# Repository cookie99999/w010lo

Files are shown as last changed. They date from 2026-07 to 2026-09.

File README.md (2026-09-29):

# A homebrew MC68010 computer

### Current specs:

- 16MHz 68010
- 1MB RAM
- 256K flash
- 68681 DUART
- A simple monitor ported from my 65816 computer, with XMODEM download support
- PATA interface (tested with several CF cards and a real IDE HDD)

### Todo:

- New PCB revision with some bodge fixes and some SMD parts to fit more memory
- Real-time clock
- Audio+video board
- PS/2 mouse + keyboard controller
- Consider networking (SLIP or ethernet controller)

### Toolchain notes

For assembly I am using vasm, since I like the syntax better than GAS. For C, I built a cross-compiling GCC and binutils from source. When configuring GCC for a 68000/68008/68010 target, you have to be careful not to let it use any 68020+ or FPU specific instructions, or else your libgcc won't work. Here's the line I used to configure mine:
```
../gcc-15.2.0/configure --prefix=/home/cookie/.local/ --program-prefix=m68k-elf- --target=m68k-elf --with-cpu=m68000 --enable-languages=c --with-newlib --disable-libssp --disable-libgomp --disable-threads --disable-multilib --disable-nls --disable-libquadmath --without-headers --disable-m68020 --disable-m68881
```
Some of the less obvious options may not be strictly necessary, I haven't tested with and without each one.
With just a compiler, binutils, and libgcc, you have pretty much all you need to comfortably write and use C programs. I have ported newlib+libgloss, but have some minor bugs to work out. I will eventually write up the process, as a lot of the documentation online is outdated by this point.

###

Shoutout to [aslak](https://www.aslak.net/), [rosco-m68k](https://github.com/rosco-m68k), [68-Katy](https://www.bigmessowires.com/68-katy/), [Matt Sarnoff](https://github.com/74hc595/68k-nano), [Jeff Tranter](https://jefftranter.blogspot.com/), and [Mackerel-68k](https://hackaday.io/project/183861-mackerel-68k-linux-sbcs) for their inspiring projects and helpful logs.

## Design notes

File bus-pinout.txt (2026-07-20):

96 Pin 3x32 DIN 41612
A       | B      | C
--------------------------
D0      | NC     | D8
D1      | NC     | D9
D2      | NC     | D10
D3      | NC     | D11
D4      | NC     | D12
D5      | NC     | D13
D6      | NC     | D14
D7      | NC     | D15
GND     | NC     | GND
CLK     | NC     | NC
GND     | NC     | !BERR
!UDS    | NC     | !RESET
!LDS    | NC     | NC
R/!W    | NC     | NC
GND     | NC     | A23
!DTACK  | GND    | A22
GND     | !VMA   | A21
!AS     | E      | A20
GND     | !VPA   | A19
!IACK   | GND    | A18
!IACKIN | NC     | A17
!IACKOUT| NC     | A16
NC      | GND    | A15
A7      | !IRQ7  | A14
A6      | !IRQ6  | A13
A5      | !IRQ5  | A12
A4      | !IRQ4  | A11
A3      | !IRQ3  | A10
A2      | !IRQ2  | A9
A1      | !IRQ1  | A8
NC      | +5V    | NC
+5V     | +5V    | +5V

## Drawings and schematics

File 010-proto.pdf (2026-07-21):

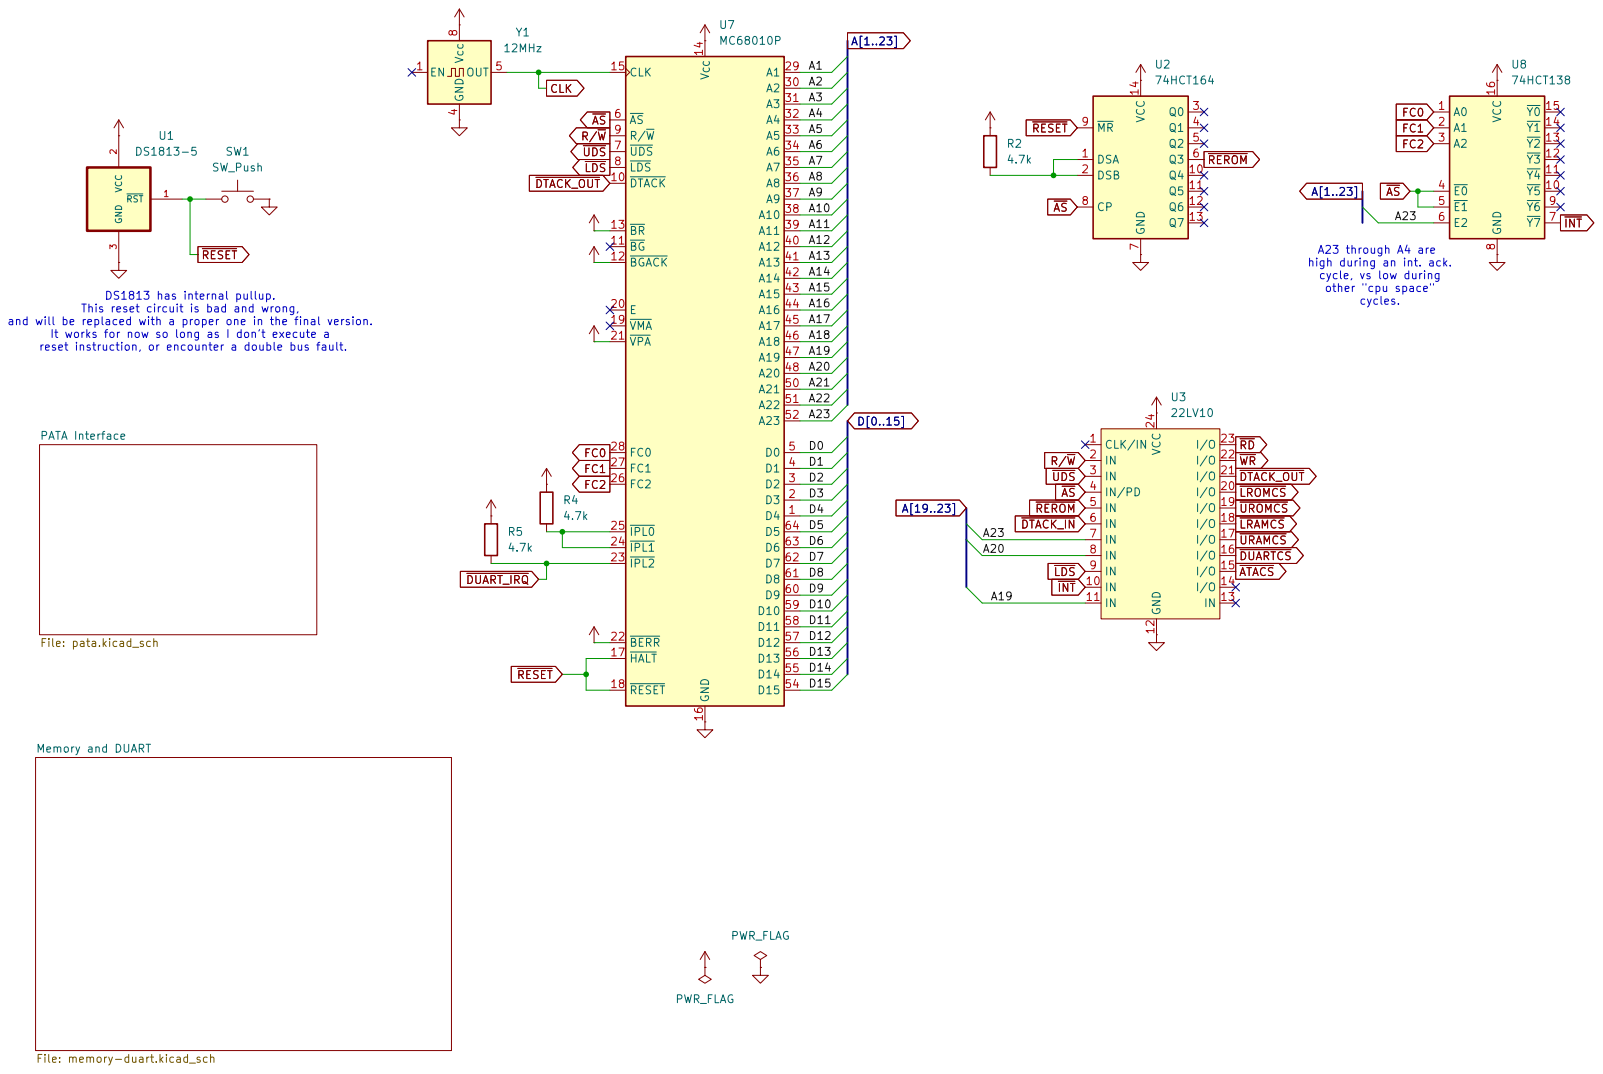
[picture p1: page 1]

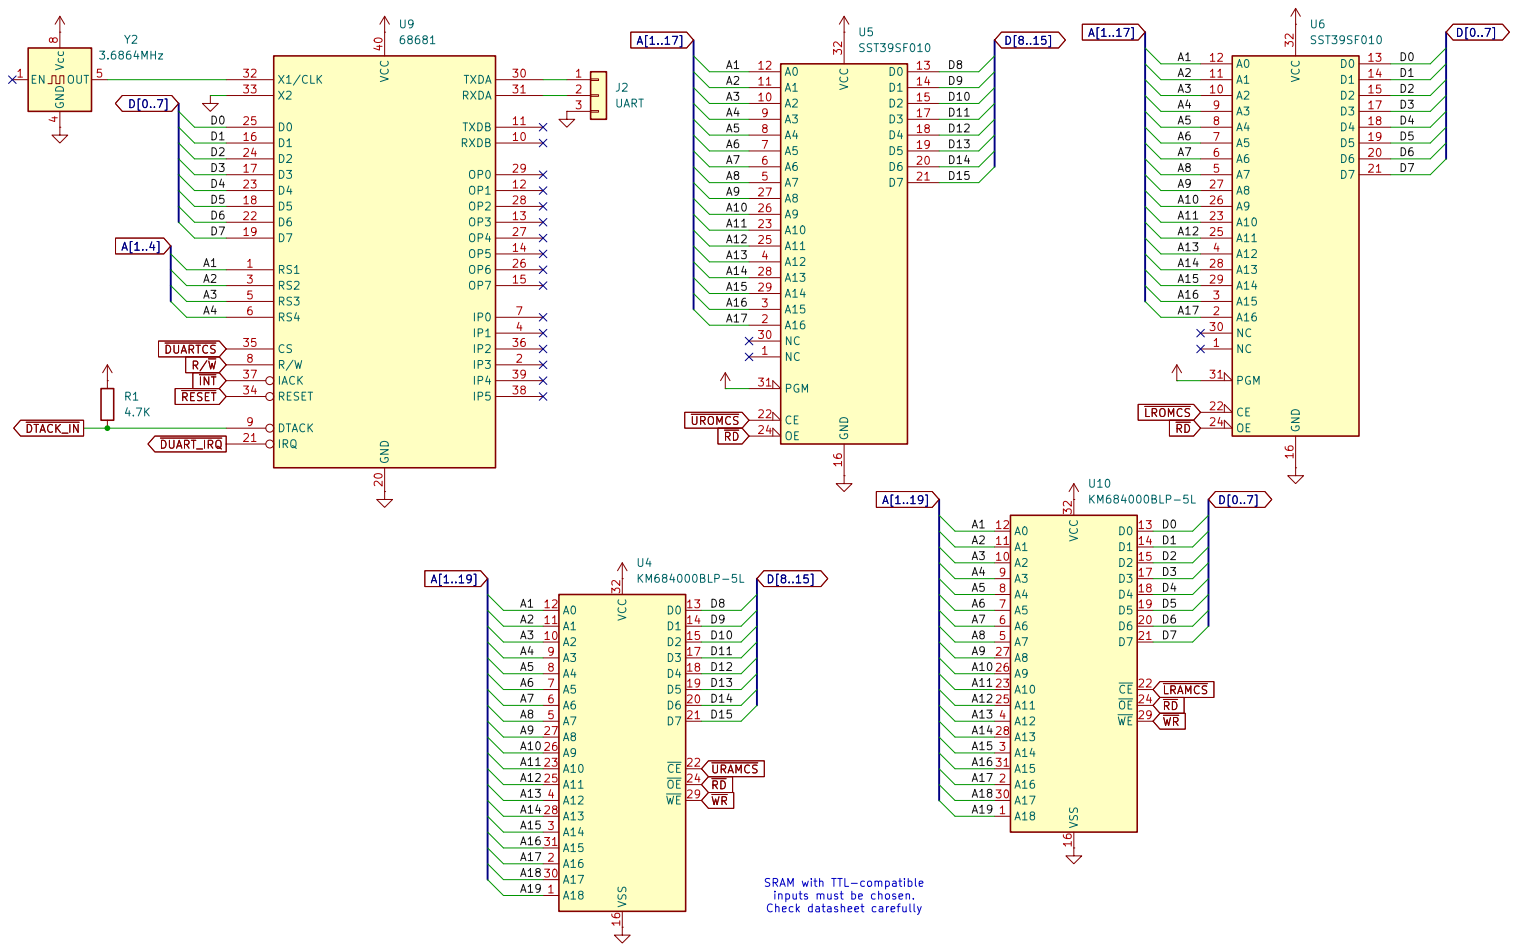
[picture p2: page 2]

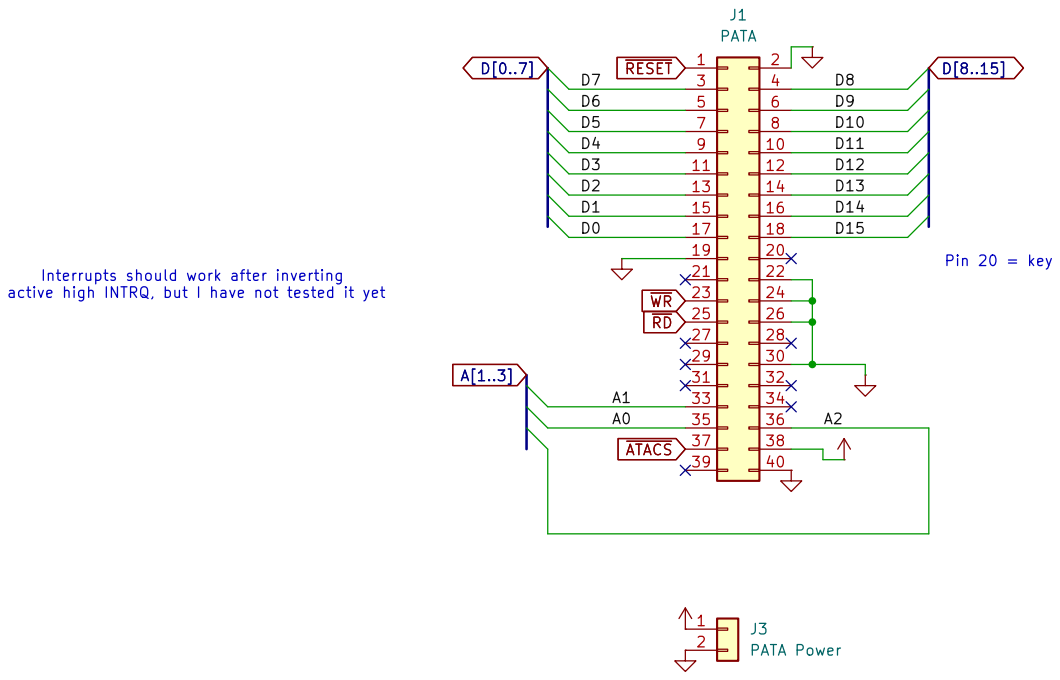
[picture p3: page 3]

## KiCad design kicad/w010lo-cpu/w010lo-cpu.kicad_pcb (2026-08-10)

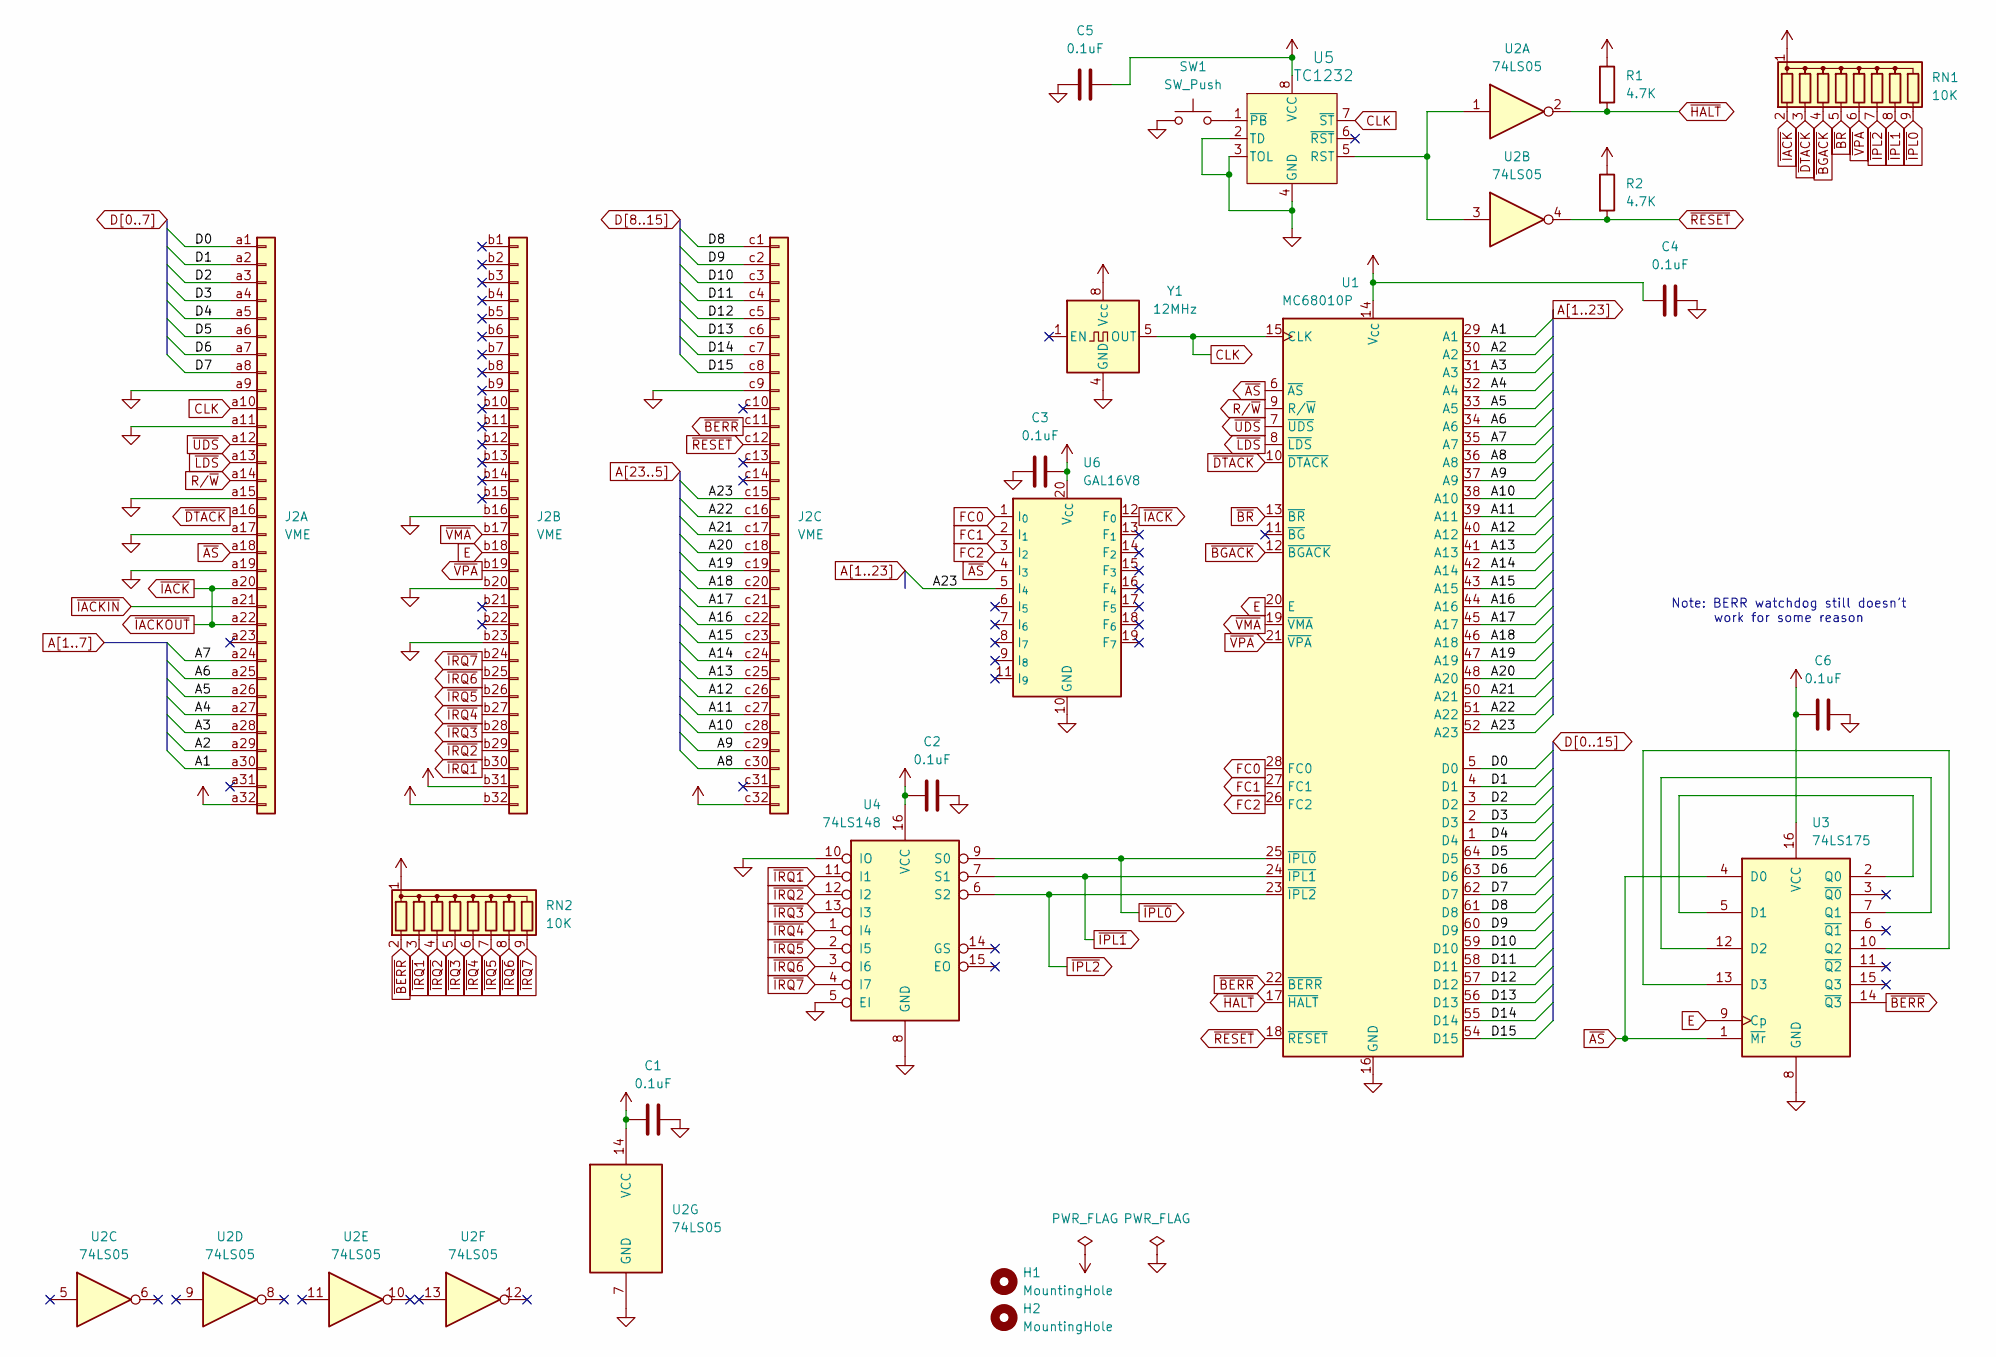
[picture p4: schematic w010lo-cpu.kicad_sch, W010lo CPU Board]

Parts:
C1, C2, C3, C4, C5, C6: 0.1uF; C_Disc_D5.0mm_W2.5mm_P5.00mm
H1, H2: MountingHole; MountingHole_3.2mm_M3
J2: VME; DIN41612_C_3x32_Male_Horizontal_THT
R1, R2: 4.7K; R_Axial_DIN0204_L3.6mm_D1.6mm_P5.08mm_Horizontal
RN1, RN2: 10K; R_Array_SIP9
SW1: SW_Push; SW_TS11-674-135-BK-160-RA-D
U1: MC68010P; DIP-64_W22.86mm
U2: 74LS05; DIP-14_W7.62mm_Socket
U3: 74LS175; DIP-16_W7.62mm_Socket
U4: 74LS148; DIP-16_W7.62mm_Socket
U5: TC1232; DIP-8_W7.62mm_Socket
U6: GAL16V8; DIP-20_W7.62mm_Socket
Y1: 12MHz; Oscillator_DIP-8

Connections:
A1: J2.a30, U1.29 (A1)
A2: J2.a29, U1.30 (A2)
A3: J2.a28, U1.31 (A3)
A4: J2.a27, U1.32 (A4)
A5: J2.a26, U1.33 (A5)
A6: J2.a25, U1.34 (A6)
A7: J2.a24, U1.35 (A7)
A8: J2.c30, U1.36 (A8)
A9: J2.c29, U1.37 (A9)
A10: J2.c28, U1.38 (A10)
A11: J2.c27, U1.39 (A11)
A12: J2.c26, U1.40 (A12)
A13: J2.c25, U1.41 (A13)
A14: J2.c24, U1.42 (A14)
A15: J2.c23, U1.43 (A15)
A16: J2.c22, U1.44 (A16)
A17: J2.c21, U1.45 (A17)
A18: J2.c20, U1.46 (A18)
A19: J2.c19, U1.47 (A19)
A20: J2.c18, U1.48 (A20)
A21: J2.c17, U1.50 (A21)
A22: J2.c16, U1.51 (A22)
A23: J2.c15, U1.52 (A23), U6.5 (I_{4})
CLK: J2.a10, U1.15 (CLK), U5.7 (~ST), Y1.5 (OUT)
D0: J2.a1, U1.5 (D0)
D1: J2.a2, U1.4 (D1)
D2: J2.a3, U1.3 (D2)
D3: J2.a4, U1.2 (D3)
D4: J2.a5, U1.1 (D4)
D5: J2.a6, U1.64 (D5)
D6: J2.a7, U1.63 (D6)
D7: J2.a8, U1.62 (D7)
D8: J2.c1, U1.61 (D8)
D9: J2.c2, U1.60 (D9)
D10: J2.c3, U1.59 (D10)
D11: J2.c4, U1.58 (D11)
D12: J2.c5, U1.57 (D12)
D13: J2.c6, U1.56 (D13)
D14: J2.c7, U1.55 (D14)
D15: J2.c8, U1.54 (D15)
E: J2.b18, U1.20 (E), U3.9 (Cp)
FC0: U1.28 (FC0), U6.1 (I_{0})
FC1: U1.27 (FC1), U6.2 (I_{1})
FC2: U1.26 (FC2), U6.3 (I_{2})
GND: C1.2, C2.2, C3.2, C4.2, C5.2, C6.2, J2.a9, J2.a11, J2.a15, J2.a17, J2.a19, J2.b16, J2.b20, J2.b23, J2.c9, SW1.1, U1.16 (GND), U1.53 (GND), U2.7 (GND), U3.8 (GND), U4.5 (EI), U4.8 (GND), U4.10 (IO), U5.2 (TD), U5.3 (TOL), U5.4 (GND), U6.10 (GND), Y1.4 (GND)
unnamed: U3.2 (Q0), U3.5 (D1)
unnamed: U3.7 (Q1), U3.12 (D2)
unnamed: U3.10 (Q2), U3.13 (D3)
unnamed: U2.1, U2.3, U5.5 (RST)
unnamed: SW1.2, U5.1 (~PB)
R/~W: J2.a14, U1.9 (R/~W)
VCC: C1.1, C2.1, C3.1, C4.1, C5.1, C6.1, J2.a32, J2.b31, J2.b32, J2.c32, R1.1, R2.1, RN1.1 (common), RN2.1 (common), U1.14 (V_{CC}), U1.49 (V_{CC}), U2.14 (VCC), U3.16 (VCC), U4.16 (VCC), U5.8 (VCC), U6.20 (V_{CC}), Y1.8 (Vcc)
~AS: J2.a18, U1.6 (~AS), U3.1 (~Mr), U3.4 (D0), U6.4 (I_{3})
~BERR: J2.c11, RN2.2 (R1), U1.22 (~BERR), U3.14 (~Q3)
~BGACK: RN1.4 (R3), U1.12 (~BGACK)
~BR: RN1.5 (R4), U1.13 (~BR)
~DTACK: J2.a16, RN1.3 (R2), U1.10 (~DTACK)
~HALT: R1.2, U1.17 (~HALT), U2.2
~IACKIN: J2.a21
~IACKOUT: J2.a20, J2.a22, RN1.2 (R1), U6.12 (F_{0})
~IPL0: RN1.9 (R8), U1.25 (~IPL0), U4.9 (S0)
~IPL1: RN1.8 (R7), U1.24 (~IPL1), U4.7 (S1)
~IPL2: RN1.7 (R6), U1.23 (~IPL2), U4.6 (S2)
~IRQ1: J2.b30, RN2.3 (R2), U4.11 (I1)
~IRQ2: J2.b29, RN2.4 (R3), U4.12 (I2)
~IRQ3: J2.b28, RN2.5 (R4), U4.13 (I3)
~IRQ4: J2.b27, RN2.6 (R5), U4.1 (I4)
~IRQ5: J2.b26, RN2.7 (R6), U4.2 (I5)
~IRQ6: J2.b25, RN2.8 (R7), U4.3 (I6)
~IRQ7: J2.b24, RN2.9 (R8), U4.4 (I7)
~LDS: J2.a13, U1.8 (~LDS)
~RESET: J2.c12, R2.2, U1.18 (~RESET), U2.4
~UDS: J2.a12, U1.7 (~UDS)
~VMA: J2.b17, U1.19 (~VMA)
~VPA: J2.b19, RN1.6 (R5), U1.21 (~VPA)

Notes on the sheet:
Note: BERR watchdog still doesn't work for some reason

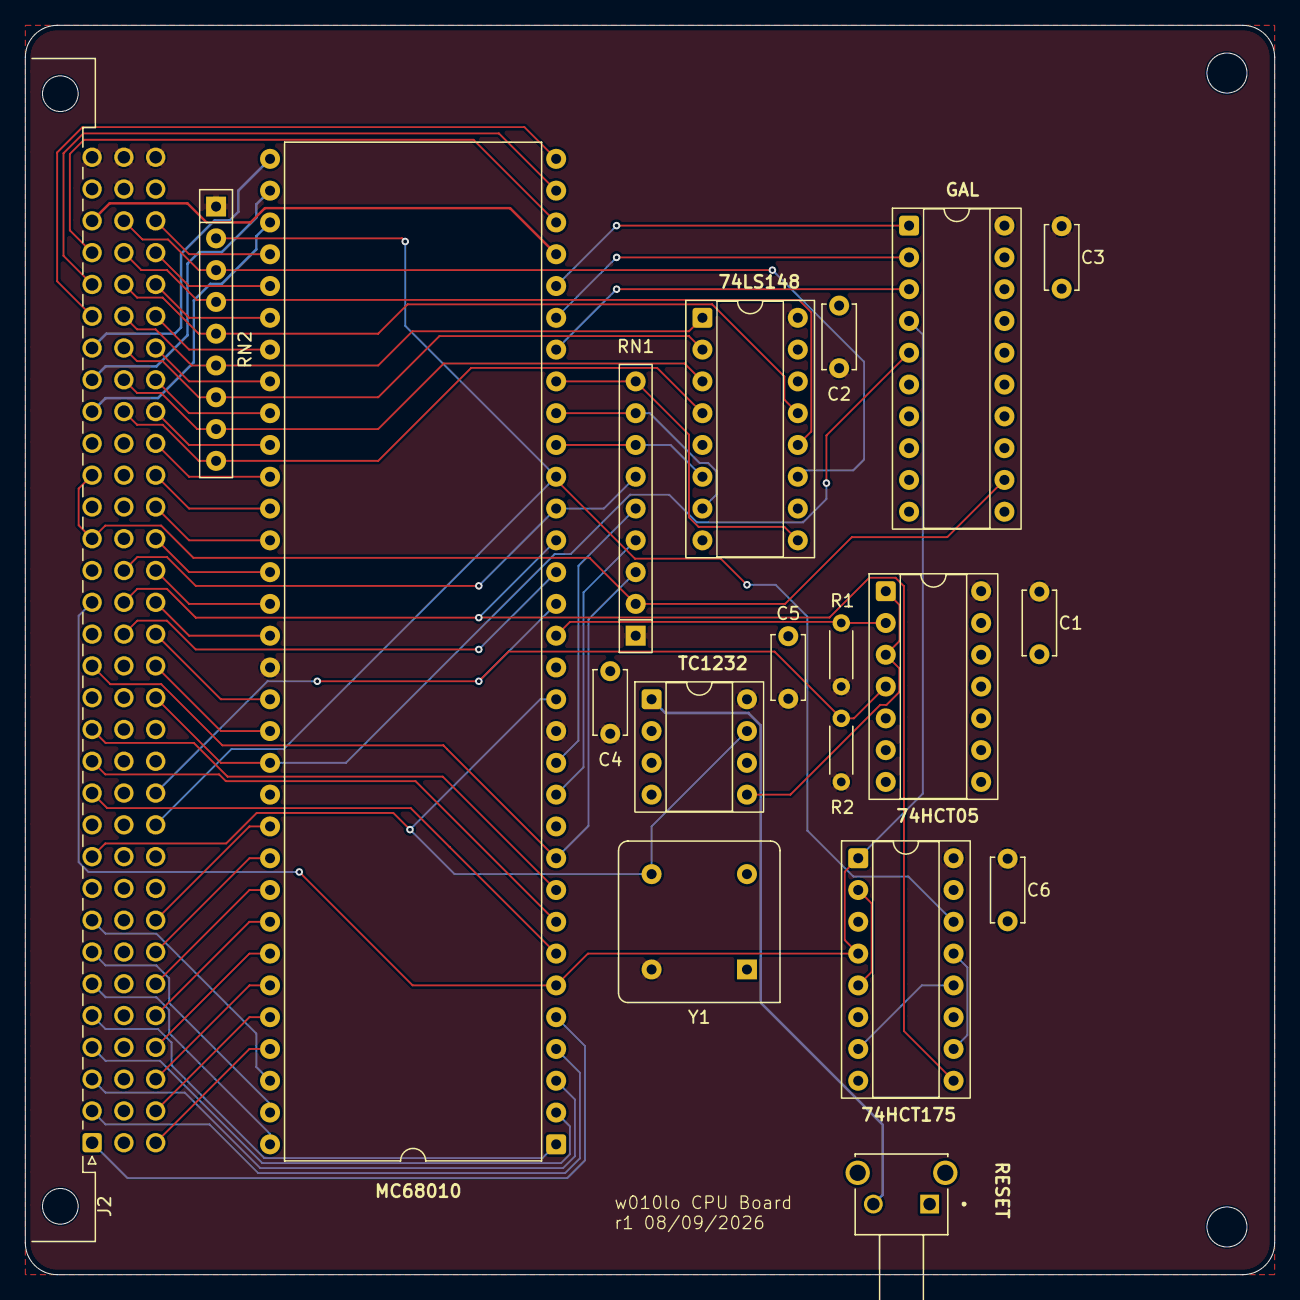
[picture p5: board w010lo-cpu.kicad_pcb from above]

Board: 4 copper layers, 99.8 x 99.8 mm, 22 parts (0 on the bottom side), 74 nets.

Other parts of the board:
H3: MountingHole; MountingHole_3.2mm_M3

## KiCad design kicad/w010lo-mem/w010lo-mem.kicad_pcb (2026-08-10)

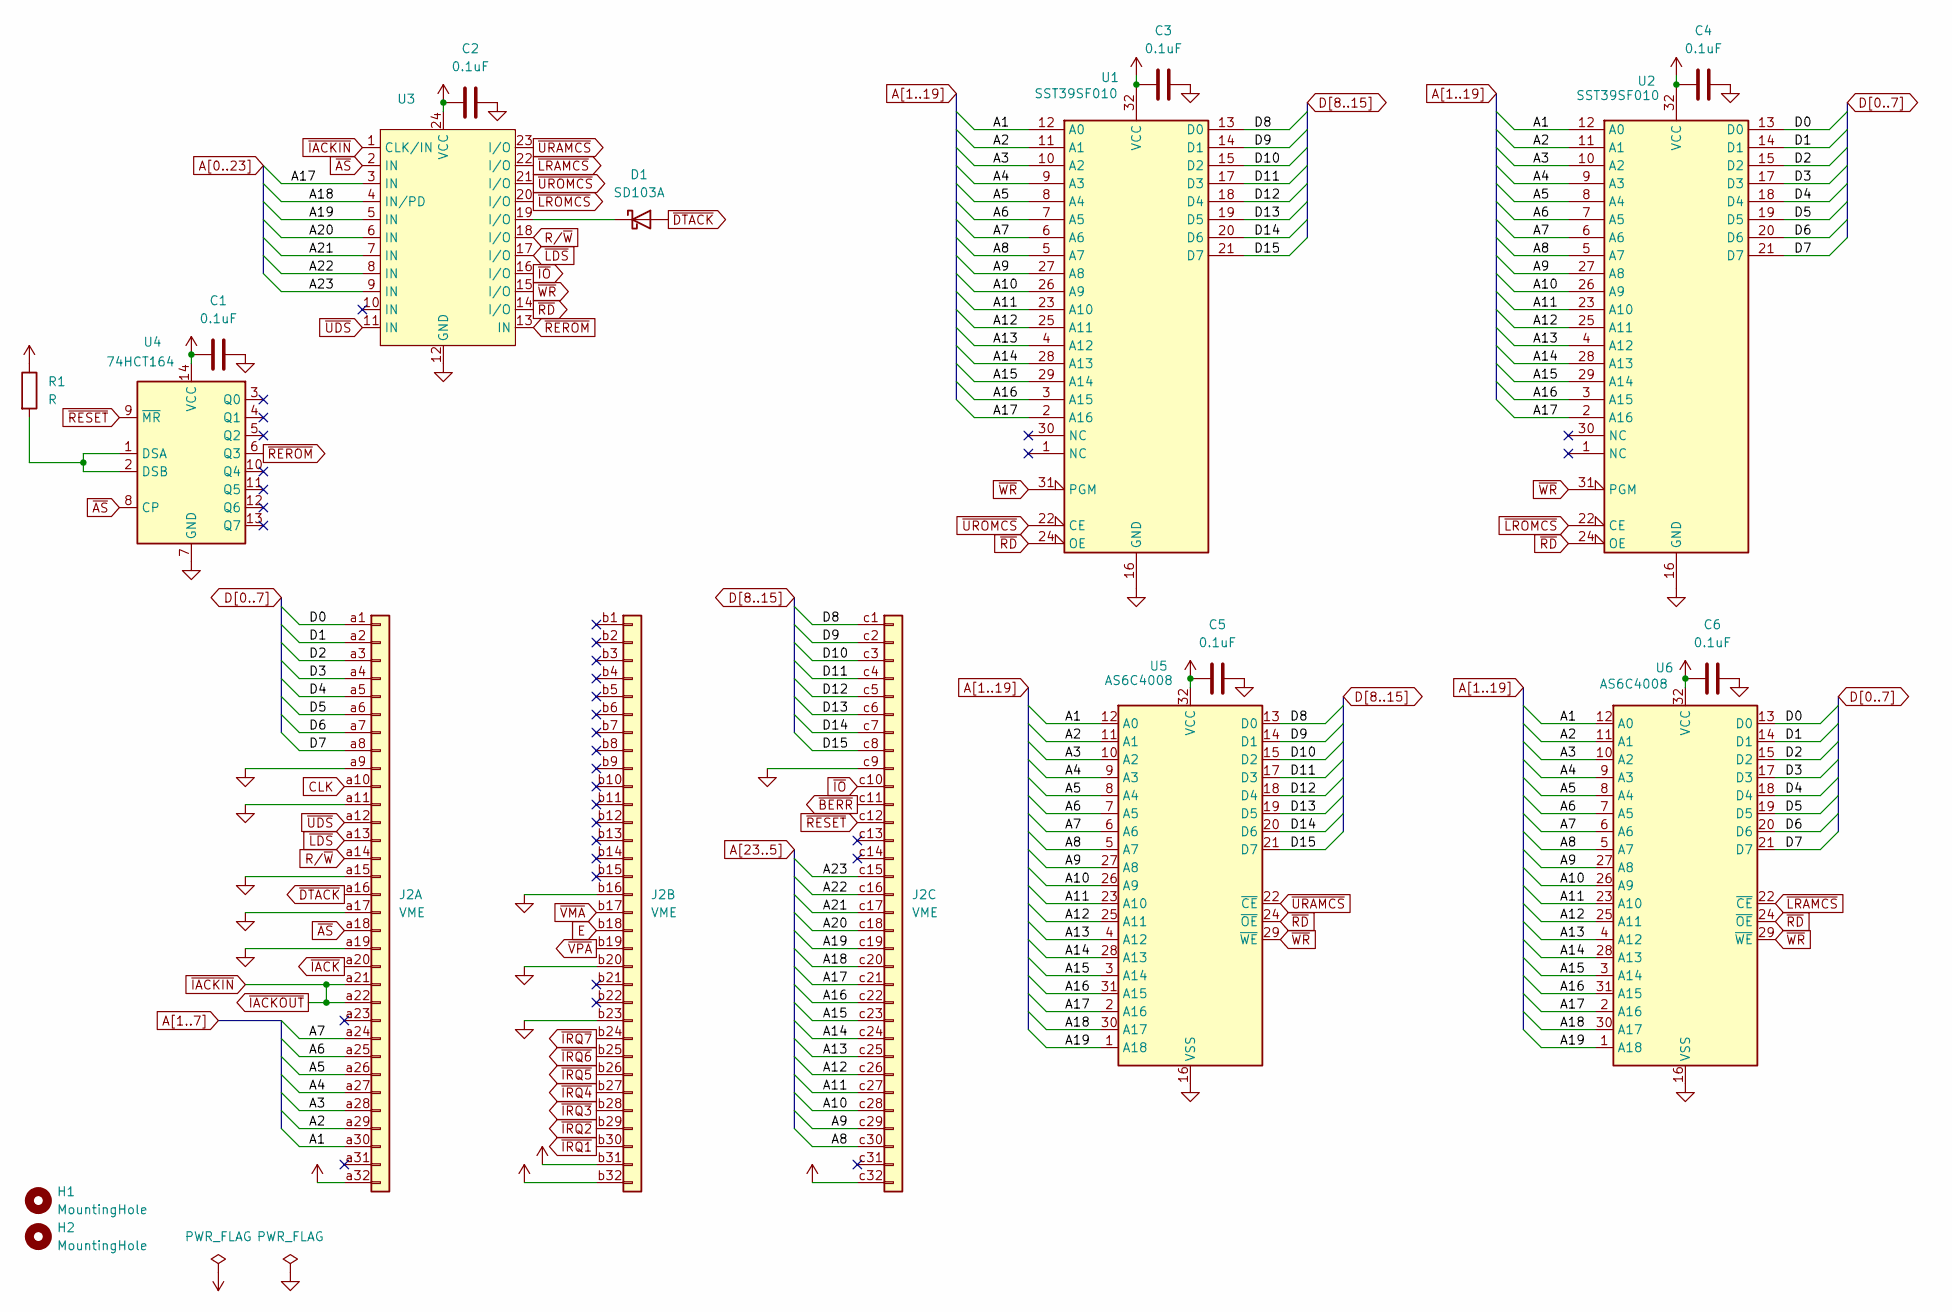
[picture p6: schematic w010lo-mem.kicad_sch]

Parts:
C1, C2, C3, C4, C5, C6: 0.1uF; C_Disc_D5.0mm_W2.5mm_P5.00mm
D1: SD103A; D_DO-35_SOD27_P7.62mm_Horizontal
H1, H2: MountingHole; MountingHole_3.2mm_M3
J2: VME; DIN41612_C_3x32_Male_Horizontal_THT
R1: R; R_Axial_DIN0207_L6.3mm_D2.5mm_P7.62mm_Horizontal
U1, U2: SST39SF010; DIP-32_W15.24mm_Socket
U3: DIP-24_W7.62mm_Socket
U4: 74HCT164; DIP-14_W7.62mm_Socket
U5, U6: AS6C4008; DIP-32_W15.24mm_Socket

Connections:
A1: J2.a30, U1.12 (A0), U2.12 (A0), U5.12 (A0), U6.12 (A0)
A2: J2.a29, U1.11 (A1), U2.11 (A1), U5.11 (A1), U6.11 (A1)
A3: J2.a28, U1.10 (A2), U2.10 (A2), U5.10 (A2), U6.10 (A2)
A4: J2.a27, U1.9 (A3), U2.9 (A3), U5.9 (A3), U6.9 (A3)
A5: J2.a26, U1.8 (A4), U2.8 (A4), U5.8 (A4), U6.8 (A4)
A6: J2.a25, U1.7 (A5), U2.7 (A5), U5.7 (A5), U6.7 (A5)
A7: J2.a24, U1.6 (A6), U2.6 (A6), U5.6 (A6), U6.6 (A6)
A8: J2.c30, U1.5 (A7), U2.5 (A7), U5.5 (A7), U6.5 (A7)
A9: J2.c29, U1.27 (A8), U2.27 (A8), U5.27 (A8), U6.27 (A8)
A10: J2.c28, U1.26 (A9), U2.26 (A9), U5.26 (A9), U6.26 (A9)
A11: J2.c27, U1.23 (A10), U2.23 (A10), U5.23 (A10), U6.23 (A10)
A12: J2.c26, U1.25 (A11), U2.25 (A11), U5.25 (A11), U6.25 (A11)
A13: J2.c25, U1.4 (A12), U2.4 (A12), U5.4 (A12), U6.4 (A12)
A14: J2.c24, U1.28 (A13), U2.28 (A13), U5.28 (A13), U6.28 (A13)
A15: J2.c23, U1.29 (A14), U2.29 (A14), U5.3 (A14), U6.3 (A14)
A16: J2.c22, U1.3 (A15), U2.3 (A15), U5.31 (A15), U6.31 (A15)
A17: J2.c21, U1.2 (A16), U2.2 (A16), U3.3 (IN), U5.2 (A16), U6.2 (A16)
A18: J2.c20, U3.4 (IN/PD), U5.30 (A17), U6.30 (A17)
A19: J2.c19, U3.5 (IN), U5.1 (A18), U6.1 (A18)
A20: J2.c18, U3.6 (IN)
A21: J2.c17, U3.7 (IN)
A22: J2.c16, U3.8 (IN)
A23: J2.c15, U3.9 (IN)
CLK: J2.a10
D0: J2.a1, U2.13 (D0), U6.13 (D0)
D1: J2.a2, U2.14 (D1), U6.14 (D1)
D2: J2.a3, U2.15 (D2), U6.15 (D2)
D3: J2.a4, U2.17 (D3), U6.17 (D3)
D4: J2.a5, U2.18 (D4), U6.18 (D4)
D5: J2.a6, U2.19 (D5), U6.19 (D5)
D6: J2.a7, U2.20 (D6), U6.20 (D6)
D7: J2.a8, U2.21 (D7), U6.21 (D7)
D8: J2.c1, U1.13 (D0), U5.13 (D0)
D9: J2.c2, U1.14 (D1), U5.14 (D1)
D10: J2.c3, U1.15 (D2), U5.15 (D2)
D11: J2.c4, U1.17 (D3), U5.17 (D3)
D12: J2.c5, U1.18 (D4), U5.18 (D4)
D13: J2.c6, U1.19 (D5), U5.19 (D5)
D14: J2.c7, U1.20 (D6), U5.20 (D6)
D15: J2.c8, U1.21 (D7), U5.21 (D7)
E: J2.b18
GND: C1.2, C2.2, C3.2, C4.2, C5.2, C6.2, J2.a9, J2.a11, J2.a15, J2.a17, J2.a19, J2.b16, J2.b20, J2.b23, J2.c9, U1.16 (GND), U2.16 (GND), U3.12 (GND), U4.7 (GND), U5.16 (VSS), U6.16 (VSS)
unnamed: D1.1 (K), U3.19 (I/O)
unnamed: R1.2, U4.1 (DSA), U4.2 (DSB)
R/~W: J2.a14, U3.18 (I/O)
VCC: C1.1, C2.1, C3.1, C4.1, C5.1, C6.1, J2.a32, J2.b31, J2.b32, J2.c32, R1.1, U1.32 (VCC), U2.32 (VCC), U3.24 (VCC), U4.14 (VCC), U5.32 (VCC), U6.32 (VCC)
~AS: J2.a18, U3.2 (IN), U4.8 (CP)
~BERR: J2.c11
~DTACK: D1.2 (A), J2.a16
~IACKIN: J2.a21, J2.a22, U3.1 (CLK/IN)
~IACK: J2.a20
~IO: J2.c10, U3.16 (I/O)
~IRQ1: J2.b30
~IRQ2: J2.b29
~IRQ3: J2.b28
~IRQ4: J2.b27
~IRQ5: J2.b26
~IRQ6: J2.b25
~IRQ7: J2.b24
~LDS: J2.a13, U3.17 (I/O)
~LRAMCS: U3.22 (I/O), U6.22 (~CE)
~LROMCS: U2.22 (CE), U3.20 (I/O)
~RD: U1.24 (OE), U2.24 (OE), U3.14 (I/O), U5.24 (~OE), U6.24 (~OE)
~REROM: U3.13 (IN), U4.6 (Q3)
~RESET: J2.c12, U4.9 (~MR)
~UDS: J2.a12, U3.11 (IN)
~URAMCS: U3.23 (I/O), U5.22 (~CE)
~UROMCS: U1.22 (CE), U3.21 (I/O)
~VMA: J2.b17
~VPA: J2.b19
~WR: U1.31 (PGM), U2.31 (PGM), U3.15 (I/O), U5.29 (~WE), U6.29 (~WE)

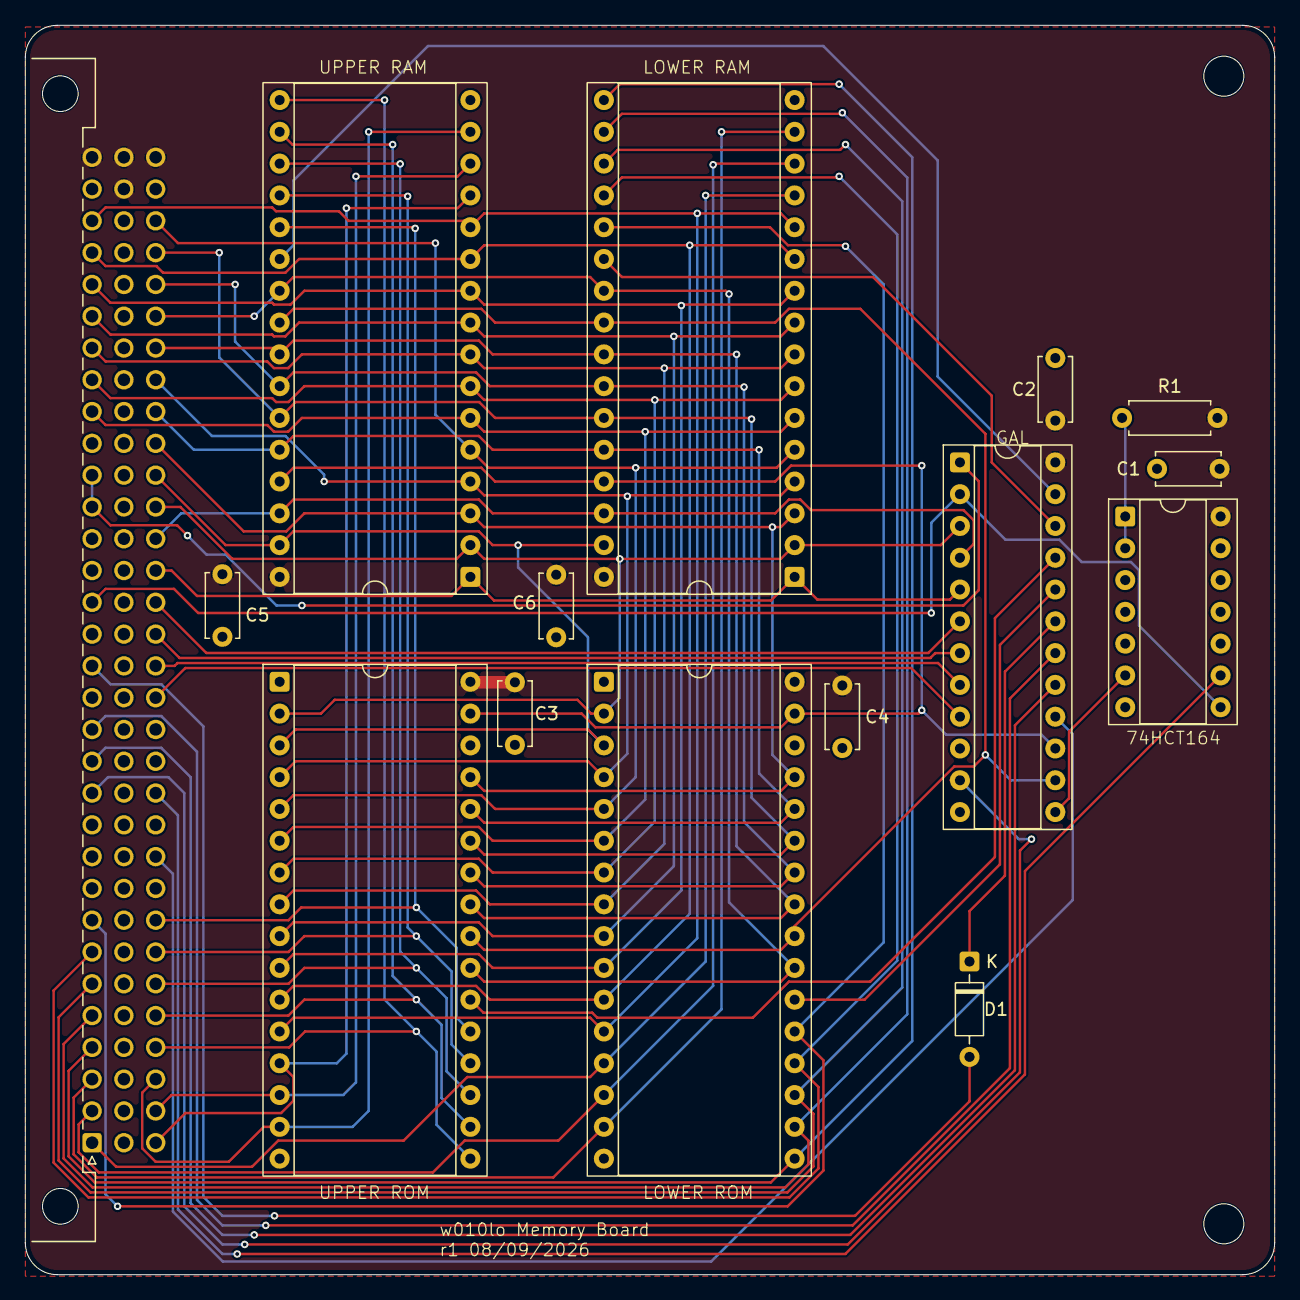
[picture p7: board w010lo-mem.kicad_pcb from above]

Board: 4 copper layers, 99.8 x 99.8 mm, 17 parts (0 on the bottom side), 58 nets.

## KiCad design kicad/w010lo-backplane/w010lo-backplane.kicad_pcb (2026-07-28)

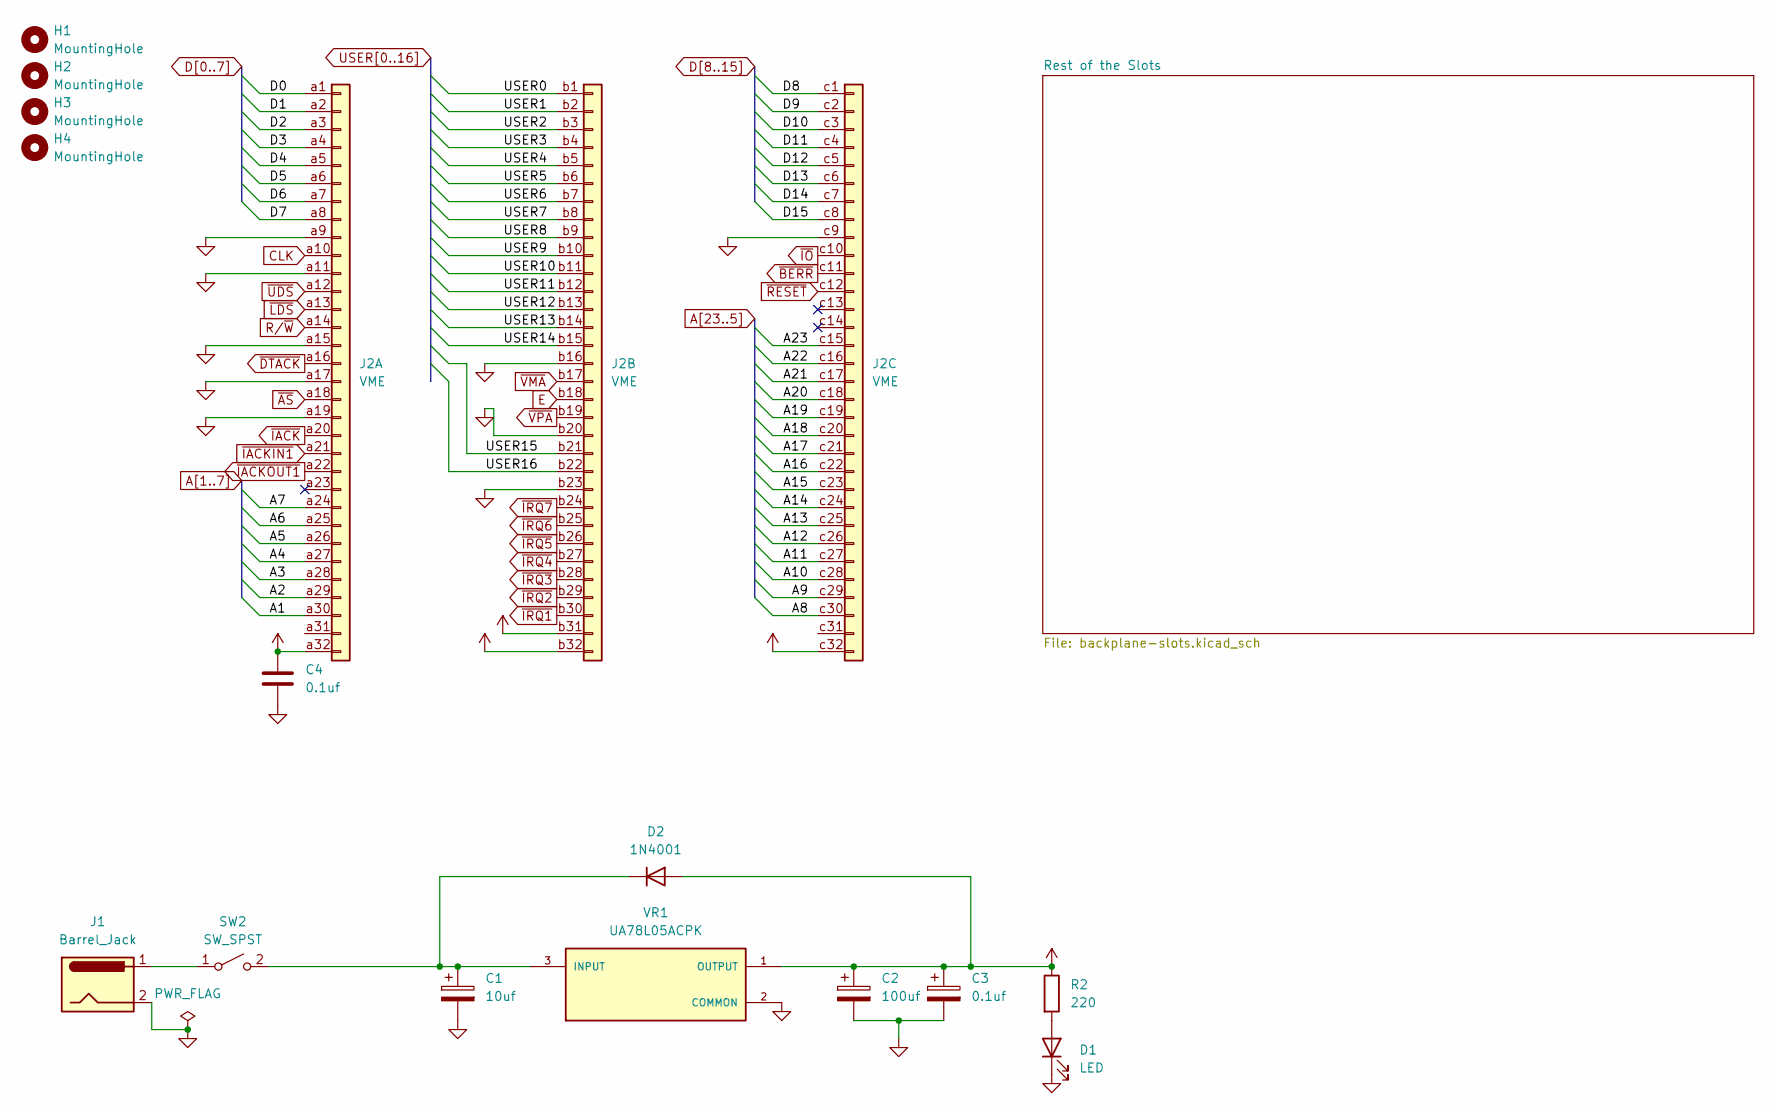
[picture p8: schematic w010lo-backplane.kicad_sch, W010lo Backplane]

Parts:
C1: 10uf; CP_Radial_D5.0mm_P2.50mm
C2: 100uf; CP_Radial_D5.0mm_P2.50mm
C3, C4: 0.1uf; C_Disc_D5.0mm_W2.5mm_P5.00mm
D1: LED; LED_D5.0mm
D2: 1N4001; D_DO-41_SOD81_P10.16mm_Horizontal
H1, H2, H3, H4: MountingHole; MountingHole_3.2mm_M3
J1: Barrel_Jack; BarrelJack_Horizontal
J2: VME; DIN41612_C_3x32_Female_Vertical_THT
R2: 220; R_Axial_DIN0207_L6.3mm_D2.5mm_P7.62mm_Horizontal
SW2: SW_SPST; SW_Slide_SPDT_Straight_CK_OS102011MS2Q
VR1: UA78L05ACPK; TO-220-3_Vertical; PARTREV V

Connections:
A1: J2.a30; also elsewhere on the board
A2: J2.a29; also elsewhere on the board
A3: J2.a28; also elsewhere on the board
A4: J2.a27; also elsewhere on the board
A5: J2.a26; also elsewhere on the board
A6: J2.a25; also elsewhere on the board
A7: J2.a24; also elsewhere on the board
A8: J2.c30; also elsewhere on the board
A9: J2.c29; also elsewhere on the board
A10: J2.c28; also elsewhere on the board
A11: J2.c27; also elsewhere on the board
A12: J2.c26; also elsewhere on the board
A13: J2.c25; also elsewhere on the board
A14: J2.c24; also elsewhere on the board
A15: J2.c23; also elsewhere on the board
A16: J2.c22; also elsewhere on the board
A17: J2.c21; also elsewhere on the board
A18: J2.c20; also elsewhere on the board
A19: J2.c19; also elsewhere on the board
A20: J2.c18; also elsewhere on the board
A21: J2.c17; also elsewhere on the board
A22: J2.c16; also elsewhere on the board
A23: J2.c15; also elsewhere on the board
CLK: J2.a10; also elsewhere on the board
D0: J2.a1; also elsewhere on the board
D1: J2.a2; also elsewhere on the board
D2: J2.a3; also elsewhere on the board
D3: J2.a4; also elsewhere on the board
D4: J2.a5; also elsewhere on the board
D5: J2.a6; also elsewhere on the board
D6: J2.a7; also elsewhere on the board
D7: J2.a8; also elsewhere on the board
D8: J2.c1; also elsewhere on the board
D9: J2.c2; also elsewhere on the board
D10: J2.c3; also elsewhere on the board
D11: J2.c4; also elsewhere on the board
D12: J2.c5; also elsewhere on the board
D13: J2.c6; also elsewhere on the board
D14: J2.c7; also elsewhere on the board
D15: J2.c8; also elsewhere on the board
E: J2.b18; also elsewhere on the board
GND: C1.2, C2.2, C3.2, C4.2, D1.1 (K), J1.2, J2.a9, J2.a11, J2.a15, J2.a17, J2.a19, J2.b16, J2.b20, J2.b23, J2.c9, VR1.2 (COMMON); also elsewhere on the board
unnamed: D1.2 (A), R2.2
unnamed: C1.1, D2.1 (K), SW2.2 (B), VR1.3 (INPUT)
unnamed: J1.1, SW2.1 (A)
R/~W: J2.a14; also elsewhere on the board
USER0: J2.b1; also elsewhere on the board
USER1: J2.b2; also elsewhere on the board
USER2: J2.b3; also elsewhere on the board
USER3: J2.b4; also elsewhere on the board
USER4: J2.b5; also elsewhere on the board
USER5: J2.b6; also elsewhere on the board
USER6: J2.b7; also elsewhere on the board
USER7: J2.b8; also elsewhere on the board
USER8: J2.b9; also elsewhere on the board
USER9: J2.b10; also elsewhere on the board
USER10: J2.b11; also elsewhere on the board
USER11: J2.b12; also elsewhere on the board
USER12: J2.b13; also elsewhere on the board
USER13: J2.b14; also elsewhere on the board
USER14: J2.b15; also elsewhere on the board
USER15: J2.b21; also elsewhere on the board
USER16: J2.b22; also elsewhere on the board
VCC: C2.1, C3.1, C4.1, D2.2 (A), J2.a32, J2.b31, J2.b32, J2.c32, R2.1, VR1.1 (OUTPUT); also elsewhere on the board
~AS: J2.a18; also elsewhere on the board
~BERR: J2.c11; also elsewhere on the board
~DTACK: J2.a16; also elsewhere on the board
~IACKIN1: J2.a21
~IACKOUT1: J2.a22; also elsewhere on the board
~IACK: J2.a20; also elsewhere on the board
~IO: J2.c10; also elsewhere on the board
~IRQ1: J2.b30; also elsewhere on the board
~IRQ2: J2.b29; also elsewhere on the board
~IRQ3: J2.b28; also elsewhere on the board
~IRQ4: J2.b27; also elsewhere on the board
~IRQ5: J2.b26; also elsewhere on the board
~IRQ6: J2.b25; also elsewhere on the board
~IRQ7: J2.b24; also elsewhere on the board
~LDS: J2.a13; also elsewhere on the board
~RESET: J2.c12; also elsewhere on the board
~UDS: J2.a12; also elsewhere on the board
~VMA: J2.b17; also elsewhere on the board
~VPA: J2.b19; also elsewhere on the board

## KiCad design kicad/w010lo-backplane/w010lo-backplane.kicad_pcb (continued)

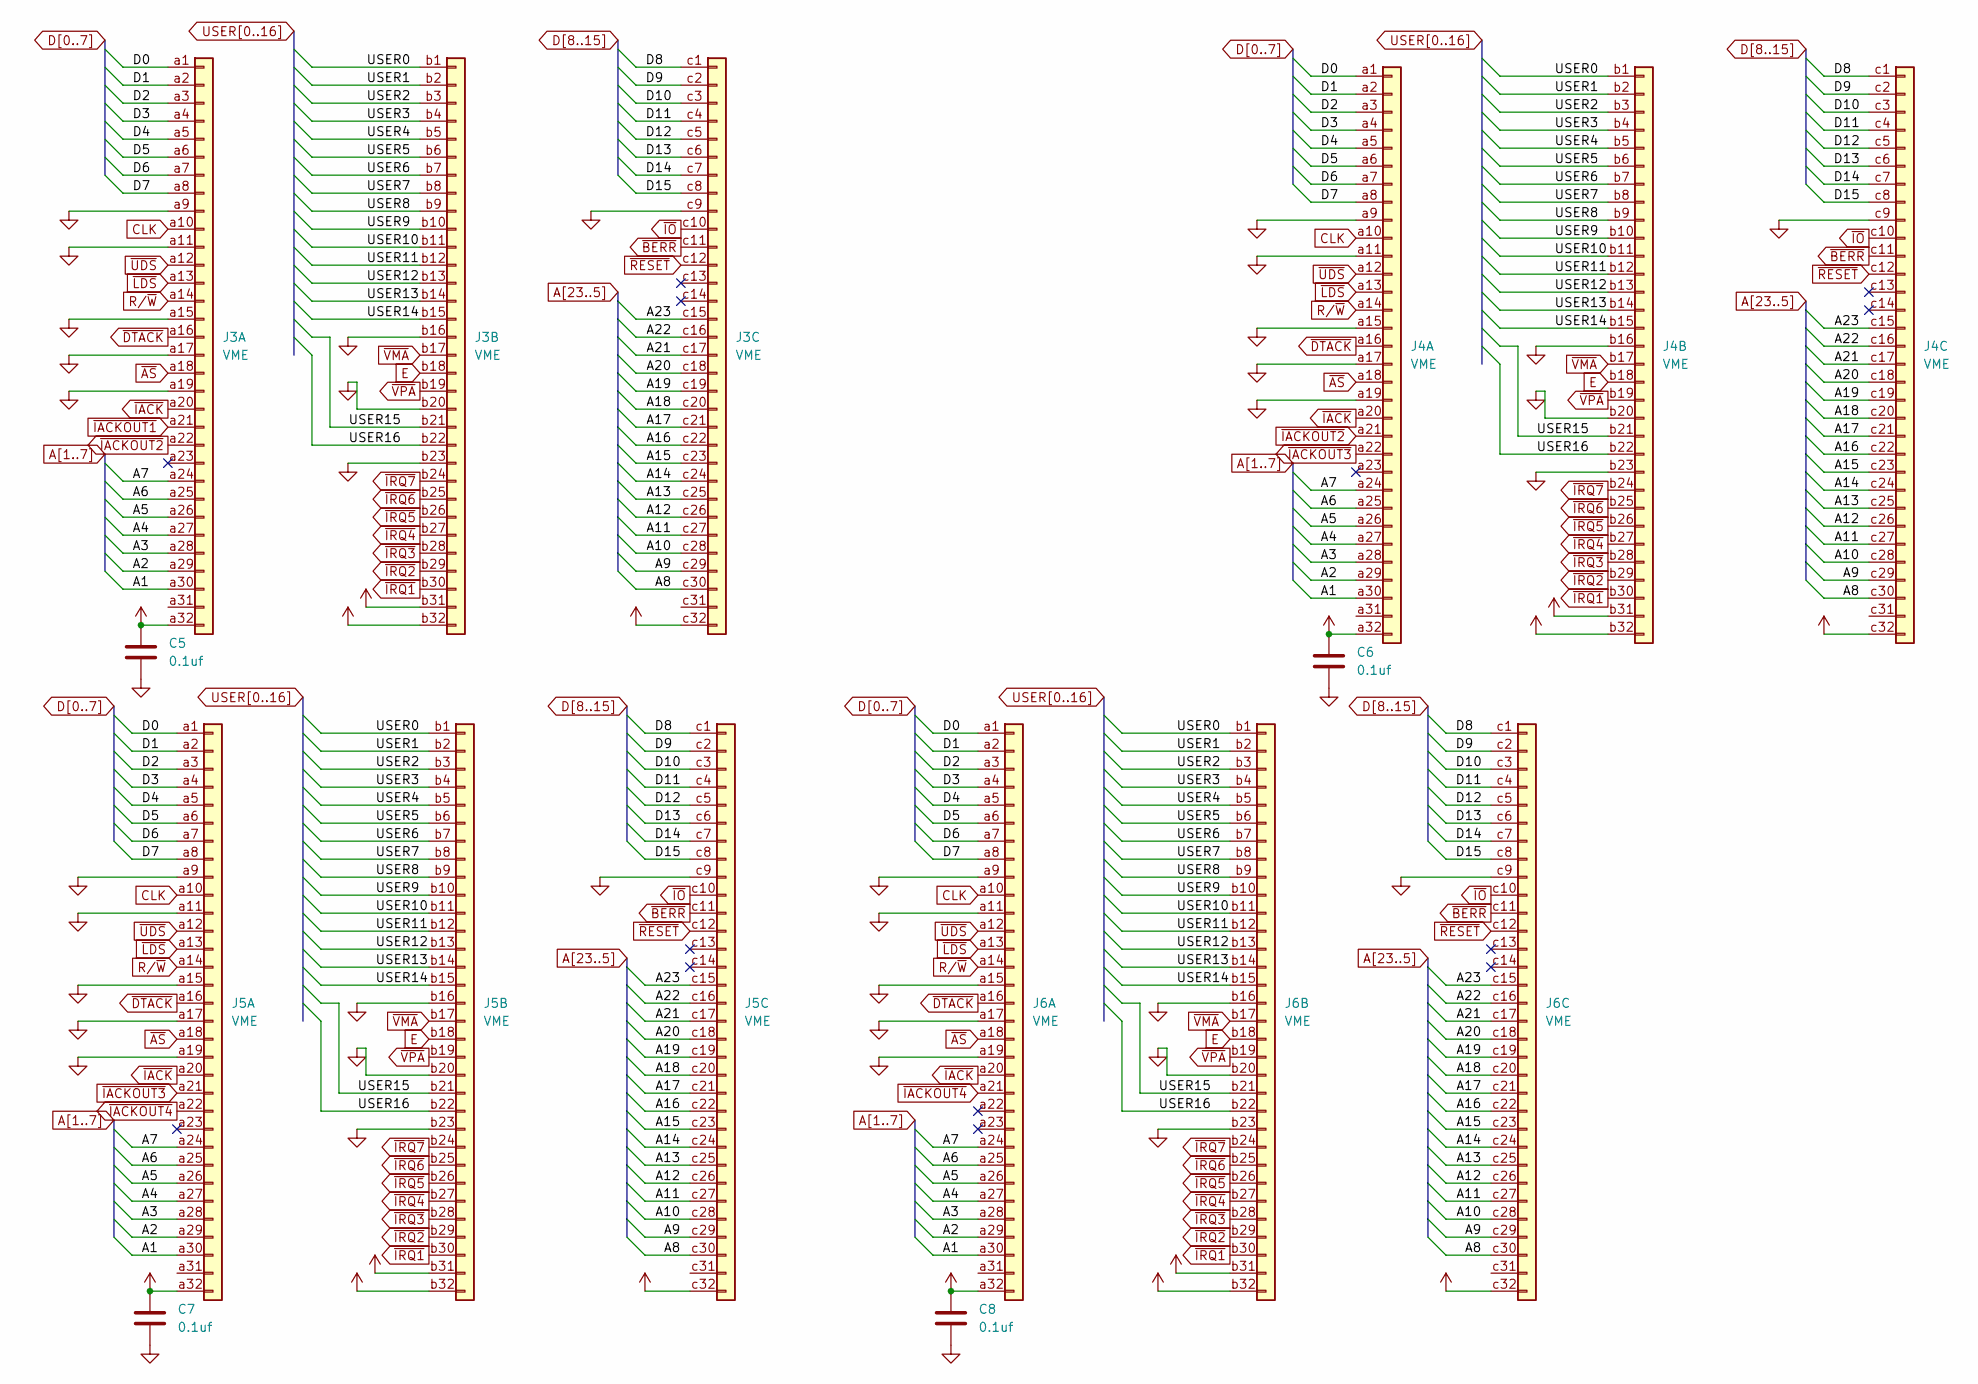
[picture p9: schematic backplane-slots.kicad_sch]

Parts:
C5, C6, C7, C8: 0.1uf; C_Disc_D5.0mm_W2.5mm_P5.00mm
J3, J4, J5, J6: VME; DIN41612_C_3x32_Female_Vertical_THT

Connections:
A1: J3.a30, J4.a30, J5.a30, J6.a30; also elsewhere on the board
A2: J3.a29, J4.a29, J5.a29, J6.a29; also elsewhere on the board
A3: J3.a28, J4.a28, J5.a28, J6.a28; also elsewhere on the board
A4: J3.a27, J4.a27, J5.a27, J6.a27; also elsewhere on the board
A5: J3.a26, J4.a26, J5.a26, J6.a26; also elsewhere on the board
A6: J3.a25, J4.a25, J5.a25, J6.a25; also elsewhere on the board
A7: J3.a24, J4.a24, J5.a24, J6.a24; also elsewhere on the board
A8: J3.c30, J4.c30, J5.c30, J6.c30; also elsewhere on the board
A9: J3.c29, J4.c29, J5.c29, J6.c29; also elsewhere on the board
A10: J3.c28, J4.c28, J5.c28, J6.c28; also elsewhere on the board
A11: J3.c27, J4.c27, J5.c27, J6.c27; also elsewhere on the board
A12: J3.c26, J4.c26, J5.c26, J6.c26; also elsewhere on the board
A13: J3.c25, J4.c25, J5.c25, J6.c25; also elsewhere on the board
A14: J3.c24, J4.c24, J5.c24, J6.c24; also elsewhere on the board
A15: J3.c23, J4.c23, J5.c23, J6.c23; also elsewhere on the board
A16: J3.c22, J4.c22, J5.c22, J6.c22; also elsewhere on the board
A17: J3.c21, J4.c21, J5.c21, J6.c21; also elsewhere on the board
A18: J3.c20, J4.c20, J5.c20, J6.c20; also elsewhere on the board
A19: J3.c19, J4.c19, J5.c19, J6.c19; also elsewhere on the board
A20: J3.c18, J4.c18, J5.c18, J6.c18; also elsewhere on the board
A21: J3.c17, J4.c17, J5.c17, J6.c17; also elsewhere on the board
A22: J3.c16, J4.c16, J5.c16, J6.c16; also elsewhere on the board
A23: J3.c15, J4.c15, J5.c15, J6.c15; also elsewhere on the board
CLK: J3.a10, J4.a10, J5.a10, J6.a10; also elsewhere on the board
D0: J3.a1, J4.a1, J5.a1, J6.a1; also elsewhere on the board
D1: J3.a2, J4.a2, J5.a2, J6.a2; also elsewhere on the board
D2: J3.a3, J4.a3, J5.a3, J6.a3; also elsewhere on the board
D3: J3.a4, J4.a4, J5.a4, J6.a4; also elsewhere on the board
D4: J3.a5, J4.a5, J5.a5, J6.a5; also elsewhere on the board
D5: J3.a6, J4.a6, J5.a6, J6.a6; also elsewhere on the board
D6: J3.a7, J4.a7, J5.a7, J6.a7; also elsewhere on the board
D7: J3.a8, J4.a8, J5.a8, J6.a8; also elsewhere on the board
D8: J3.c1, J4.c1, J5.c1, J6.c1; also elsewhere on the board
D9: J3.c2, J4.c2, J5.c2, J6.c2; also elsewhere on the board
D10: J3.c3, J4.c3, J5.c3, J6.c3; also elsewhere on the board
D11: J3.c4, J4.c4, J5.c4, J6.c4; also elsewhere on the board
D12: J3.c5, J4.c5, J5.c5, J6.c5; also elsewhere on the board
D13: J3.c6, J4.c6, J5.c6, J6.c6; also elsewhere on the board
D14: J3.c7, J4.c7, J5.c7, J6.c7; also elsewhere on the board
D15: J3.c8, J4.c8, J5.c8, J6.c8; also elsewhere on the board
E: J3.b18, J4.b18, J5.b18, J6.b18; also elsewhere on the board
GND: C5.2, C6.2, C7.2, C8.2, J3.a9, J3.a11, J3.a15, J3.a17, J3.a19, J3.b16, J3.b20, J3.b23, J3.c9, J4.a9, J4.a11, J4.a15, J4.a17, J4.a19, J4.b16, J4.b20, J4.b23, J4.c9, J5.a9, J5.a11, J5.a15, J5.a17, J5.a19, J5.b16, J5.b20, J5.b23, J5.c9, J6.a9, J6.a11, J6.a15, J6.a17, J6.a19, J6.b16, J6.b20, J6.b23, J6.c9; also elsewhere on the board
R/~W: J3.a14, J4.a14, J5.a14, J6.a14; also elsewhere on the board
USER0: J3.b1, J4.b1, J5.b1, J6.b1; also elsewhere on the board
USER1: J3.b2, J4.b2, J5.b2, J6.b2; also elsewhere on the board
USER2: J3.b3, J4.b3, J5.b3, J6.b3; also elsewhere on the board
USER3: J3.b4, J4.b4, J5.b4, J6.b4; also elsewhere on the board
USER4: J3.b5, J4.b5, J5.b5, J6.b5; also elsewhere on the board
USER5: J3.b6, J4.b6, J5.b6, J6.b6; also elsewhere on the board
USER6: J3.b7, J4.b7, J5.b7, J6.b7; also elsewhere on the board
USER7: J3.b8, J4.b8, J5.b8, J6.b8; also elsewhere on the board
USER8: J3.b9, J4.b9, J5.b9, J6.b9; also elsewhere on the board
USER9: J3.b10, J4.b10, J5.b10, J6.b10; also elsewhere on the board
USER10: J3.b11, J4.b11, J5.b11, J6.b11; also elsewhere on the board
USER11: J3.b12, J4.b12, J5.b12, J6.b12; also elsewhere on the board
USER12: J3.b13, J4.b13, J5.b13, J6.b13; also elsewhere on the board
USER13: J3.b14, J4.b14, J5.b14, J6.b14; also elsewhere on the board
USER14: J3.b15, J4.b15, J5.b15, J6.b15; also elsewhere on the board
USER15: J3.b21, J4.b21, J5.b21, J6.b21; also elsewhere on the board
USER16: J3.b22, J4.b22, J5.b22, J6.b22; also elsewhere on the board
VCC: C5.1, C6.1, C7.1, C8.1, J3.a32, J3.b31, J3.b32, J3.c32, J4.a32, J4.b31, J4.b32, J4.c32, J5.a32, J5.b31, J5.b32, J5.c32, J6.a32, J6.b31, J6.b32, J6.c32; also elsewhere on the board
~AS: J3.a18, J4.a18, J5.a18, J6.a18; also elsewhere on the board
~BERR: J3.c11, J4.c11, J5.c11, J6.c11; also elsewhere on the board
~DTACK: J3.a16, J4.a16, J5.a16, J6.a16; also elsewhere on the board
~IACKOUT1: J3.a21; also elsewhere on the board
~IACKOUT2: J3.a22, J4.a21
~IACKOUT3: J4.a22, J5.a21
~IACKOUT4: J5.a22, J6.a21
~IACK: J3.a20, J4.a20, J5.a20, J6.a20; also elsewhere on the board
~IO: J3.c10, J4.c10, J5.c10, J6.c10; also elsewhere on the board
~IRQ1: J3.b30, J4.b30, J5.b30, J6.b30; also elsewhere on the board
~IRQ2: J3.b29, J4.b29, J5.b29, J6.b29; also elsewhere on the board
~IRQ3: J3.b28, J4.b28, J5.b28, J6.b28; also elsewhere on the board
~IRQ4: J3.b27, J4.b27, J5.b27, J6.b27; also elsewhere on the board
~IRQ5: J3.b26, J4.b26, J5.b26, J6.b26; also elsewhere on the board
~IRQ6: J3.b25, J4.b25, J5.b25, J6.b25; also elsewhere on the board
~IRQ7: J3.b24, J4.b24, J5.b24, J6.b24; also elsewhere on the board
~LDS: J3.a13, J4.a13, J5.a13, J6.a13; also elsewhere on the board
~RESET: J3.c12, J4.c12, J5.c12, J6.c12; also elsewhere on the board
~UDS: J3.a12, J4.a12, J5.a12, J6.a12; also elsewhere on the board
~VMA: J3.b17, J4.b17, J5.b17, J6.b17; also elsewhere on the board
~VPA: J3.b19, J4.b19, J5.b19, J6.b19; also elsewhere on the board

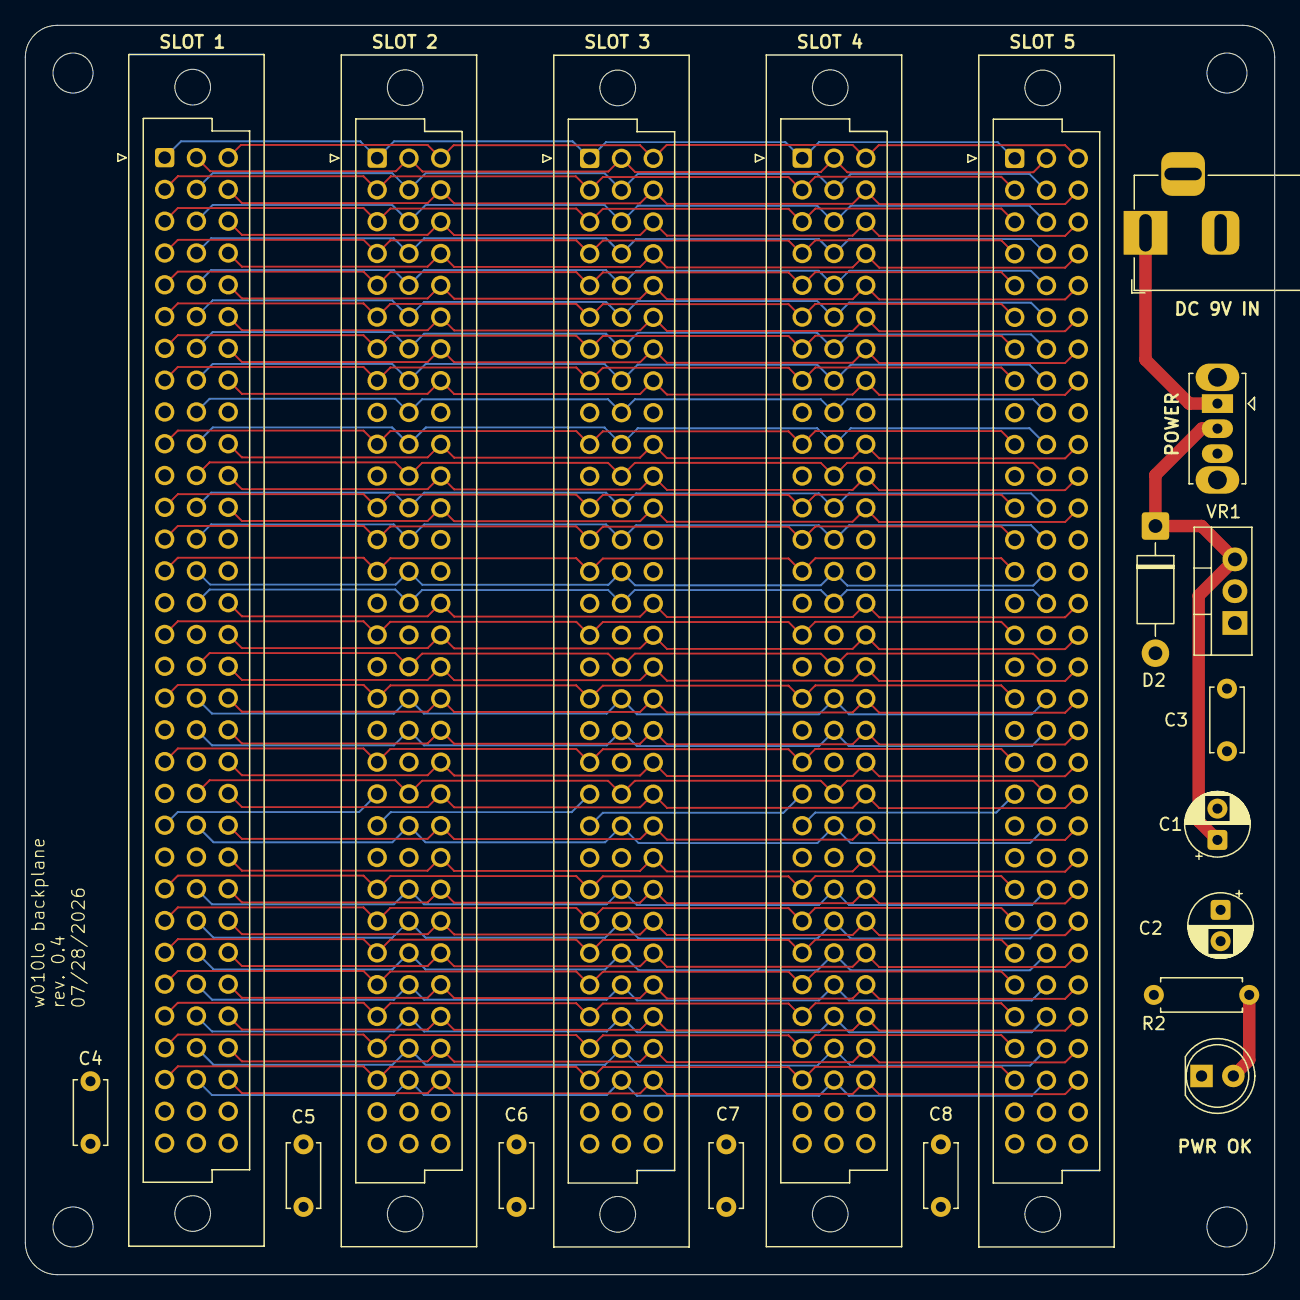
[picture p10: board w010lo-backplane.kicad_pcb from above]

Board: 4 copper layers, 99.8 x 99.8 mm, 23 parts (0 on the bottom side), 85 nets.

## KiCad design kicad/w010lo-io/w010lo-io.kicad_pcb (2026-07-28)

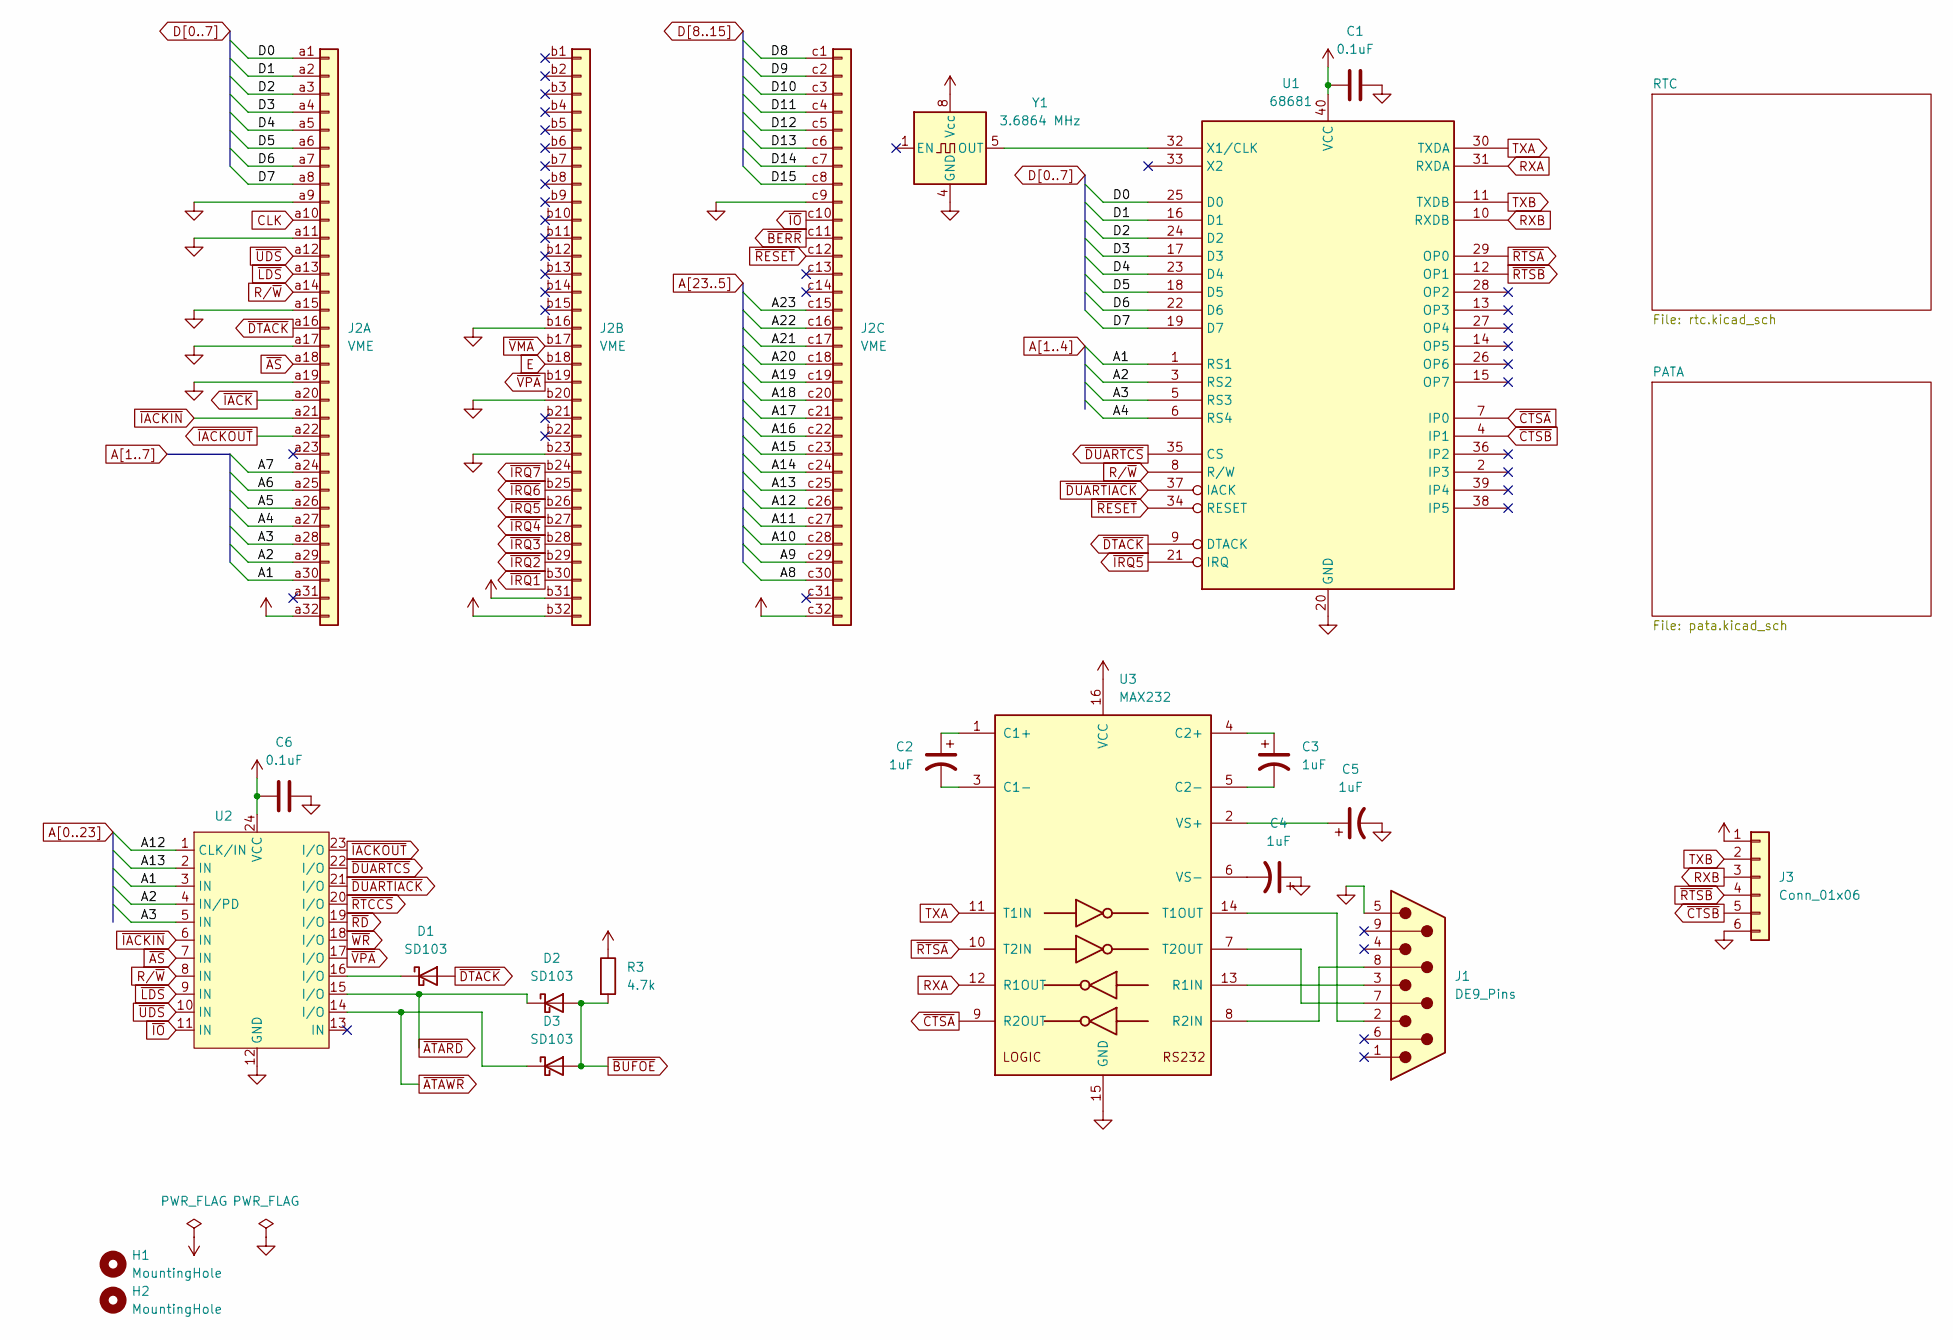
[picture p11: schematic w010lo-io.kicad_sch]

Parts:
C1, C6: 0.1uF; C_Disc_D5.0mm_W2.5mm_P5.00mm
C2, C3, C4, C5: 1uF; CP_Radial_D5.0mm_P2.50mm
D1, D2, D3: SD103; D_DO-35_SOD27_P7.62mm_Horizontal
H1, H2: MountingHole; MountingHole_3.2mm_M3
J1: DE9_Pins; DE-9-Amphenol
J2: VME; DIN41612_C_3x32_Male_Horizontal_THT
J3: Conn_01x06; PinHeader_1x06_P2.54mm_Horizontal
R3: 4.7k; R_Axial_DIN0207_L6.3mm_D2.5mm_P7.62mm_Horizontal
U1: 68681; DIP-40_W15.24mm_Socket
U2: DIP-24_W7.62mm_Socket
U3: MAX232; DIP-16_W7.62mm_Socket
Y1: 3.6864 MHz; Oscillator_DIP-8

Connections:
A1: J2.a30, U1.1 (RS1), U2.3 (IN); also elsewhere on the board
A2: J2.a29, U1.3 (RS2), U2.4 (IN/PD); also elsewhere on the board
A3: J2.a28, U1.5 (RS3), U2.5 (IN); also elsewhere on the board
A4: J2.a27, U1.6 (RS4); also elsewhere on the board
A5: J2.a26; also elsewhere on the board
A6: J2.a25; also elsewhere on the board
A7: J2.a24; also elsewhere on the board
A8: J2.c30; also elsewhere on the board
A9: J2.c29; also elsewhere on the board
A10: J2.c28; also elsewhere on the board
A11: J2.c27; also elsewhere on the board
A12: J2.c26, U2.1 (CLK/IN)
A13: J2.c25, U2.2 (IN)
A14: J2.c24
A15: J2.c23
A16: J2.c22
A17: J2.c21
A18: J2.c20
A19: J2.c19
A20: J2.c18
A21: J2.c17
A22: J2.c16
A23: J2.c15
CLK: J2.a10
D0: J2.a1, U1.25 (D0); also elsewhere on the board
D1: J2.a2, U1.16 (D1); also elsewhere on the board
D2: J2.a3, U1.24 (D2); also elsewhere on the board
D3: J2.a4, U1.17 (D3); also elsewhere on the board
D4: J2.a5, U1.23 (D4); also elsewhere on the board
D5: J2.a6, U1.18 (D5); also elsewhere on the board
D6: J2.a7, U1.22 (D6); also elsewhere on the board
D7: J2.a8, U1.19 (D7); also elsewhere on the board
D8: J2.c1; also elsewhere on the board
D9: J2.c2; also elsewhere on the board
D10: J2.c3; also elsewhere on the board
D11: J2.c4; also elsewhere on the board
D12: J2.c5; also elsewhere on the board
D13: J2.c6; also elsewhere on the board
D14: J2.c7; also elsewhere on the board
D15: J2.c8; also elsewhere on the board
E: J2.b18
GND: C1.2, C4.1, C5.2, C6.2, J1.5, J2.a9, J2.a11, J2.a15, J2.a17, J2.a19, J2.b16, J2.b20, J2.b23, J2.c9, J3.6, U1.20 (GND), U2.12 (GND), U3.15 (GND), Y1.4 (GND); also elsewhere on the board
unnamed: D1.1 (K), U2.16 (I/O)
unnamed: U1.32 (X1/CLK), Y1.5 (OUT)
unnamed: C2.1, U3.1 (C1+)
unnamed: C2.2, U3.3 (C1-)
unnamed: C3.1, U3.4 (C2+)
unnamed: C3.2, U3.5 (C2-)
unnamed: J1.3, U3.13 (R1IN)
unnamed: J1.8, U3.8 (R2IN)
unnamed: J1.2, U3.14 (T1OUT)
unnamed: J1.7, U3.7 (T2OUT)
unnamed: C5.1, U3.2 (VS+)
unnamed: C4.2, U3.6 (VS-)
RXA: U1.31 (RXDA), U3.12 (R1OUT)
RXB: J3.3, U1.10 (RXDB)
R/~W: J2.a14, U1.8 (R/W), U2.8 (IN); also elsewhere on the board
TXA: U1.30 (TXDA), U3.11 (T1IN)
TXB: J3.2, U1.11 (TXDB)
VCC: C1.1, C6.1, J2.a32, J2.b31, J2.b32, J2.c32, J3.1, R3.1, U1.40 (VCC), U2.24 (VCC), U3.16 (VCC), Y1.8 (Vcc); also elsewhere on the board
~AS: J2.a18, U2.7 (IN)
~ATARD: D2.1 (K), U2.15 (I/O); also elsewhere on the board
~ATAWR: D3.1 (K), U2.14 (I/O); also elsewhere on the board
~BERR: J2.c11
~BUFOE: D2.2 (A), D3.2 (A), R3.2; also elsewhere on the board
~CTSA: U1.7 (IP0), U3.9 (R2OUT)
~CTSB: J3.5, U1.4 (IP1)
~DTACK: D1.2 (A), J2.a16, U1.9 (DTACK)
~DUARTCS: U1.35 (CS), U2.22 (I/O)
~DUARTIACK: U1.37 (IACK), U2.21 (I/O)
~IACKIN: J2.a21, U2.6 (IN)
~IACKOUT: J2.a22, U2.23 (I/O)
~IACK: J2.a20
~IO: J2.c10, U2.11 (IN)
~IRQ1: J2.b30
~IRQ2: J2.b29
~IRQ3: J2.b28; also elsewhere on the board
~IRQ4: J2.b27
~IRQ5: J2.b26, U1.21 (IRQ)
~IRQ6: J2.b25
~IRQ7: J2.b24
~LDS: J2.a13, U2.9 (IN)
~RD: U2.19 (I/O); also elsewhere on the board
~RESET: J2.c12, U1.34 (RESET); also elsewhere on the board
~RTCCS: U2.20 (I/O); also elsewhere on the board
~RTSA: U1.29 (OP0), U3.10 (T2IN)
~RTSB: J3.4, U1.12 (OP1)
~UDS: J2.a12, U2.10 (IN)
~VMA: J2.b17
~VPA: J2.b19, U2.17 (I/O)
~WR: U2.18 (I/O); also elsewhere on the board

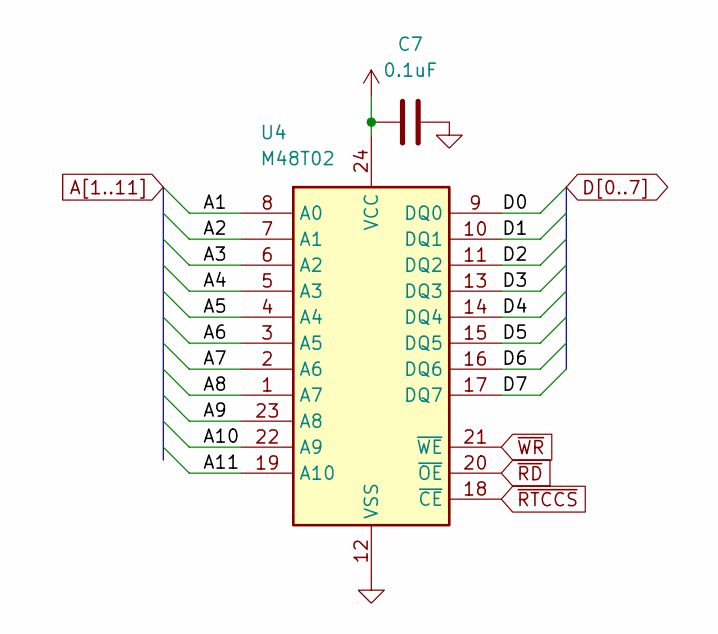
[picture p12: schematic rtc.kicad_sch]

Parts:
C7: 0.1uF; C_Disc_D5.0mm_W2.5mm_P5.00mm
U4: M48T02; DIP1562W53P279L3454H965Q24N; Mouser Part Number 511-M48T0270PC1

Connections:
A1: U4.8 (A0); also elsewhere on the board
A2: U4.7 (A1); also elsewhere on the board
A3: U4.6 (A2); also elsewhere on the board
A4: U4.5 (A3); also elsewhere on the board
A5: U4.4 (A4); also elsewhere on the board
A6: U4.3 (A5); also elsewhere on the board
A7: U4.2 (A6); also elsewhere on the board
A8: U4.1 (A7); also elsewhere on the board
A9: U4.23 (A8); also elsewhere on the board
A10: U4.22 (A9); also elsewhere on the board
A11: U4.19 (A10); also elsewhere on the board
D0: U4.9 (DQ0); also elsewhere on the board
D1: U4.10 (DQ1); also elsewhere on the board
D2: U4.11 (DQ2); also elsewhere on the board
D3: U4.13 (DQ3); also elsewhere on the board
D4: U4.14 (DQ4); also elsewhere on the board
D5: U4.15 (DQ5); also elsewhere on the board
D6: U4.16 (DQ6); also elsewhere on the board
D7: U4.17 (DQ7); also elsewhere on the board
GND: C7.2, U4.12 (VSS); also elsewhere on the board
VCC: C7.1, U4.24 (VCC); also elsewhere on the board
~RD: U4.20 (~OE); also elsewhere on the board
~RTCCS: U4.18 (~CE); also elsewhere on the board
~WR: U4.21 (~WE); also elsewhere on the board

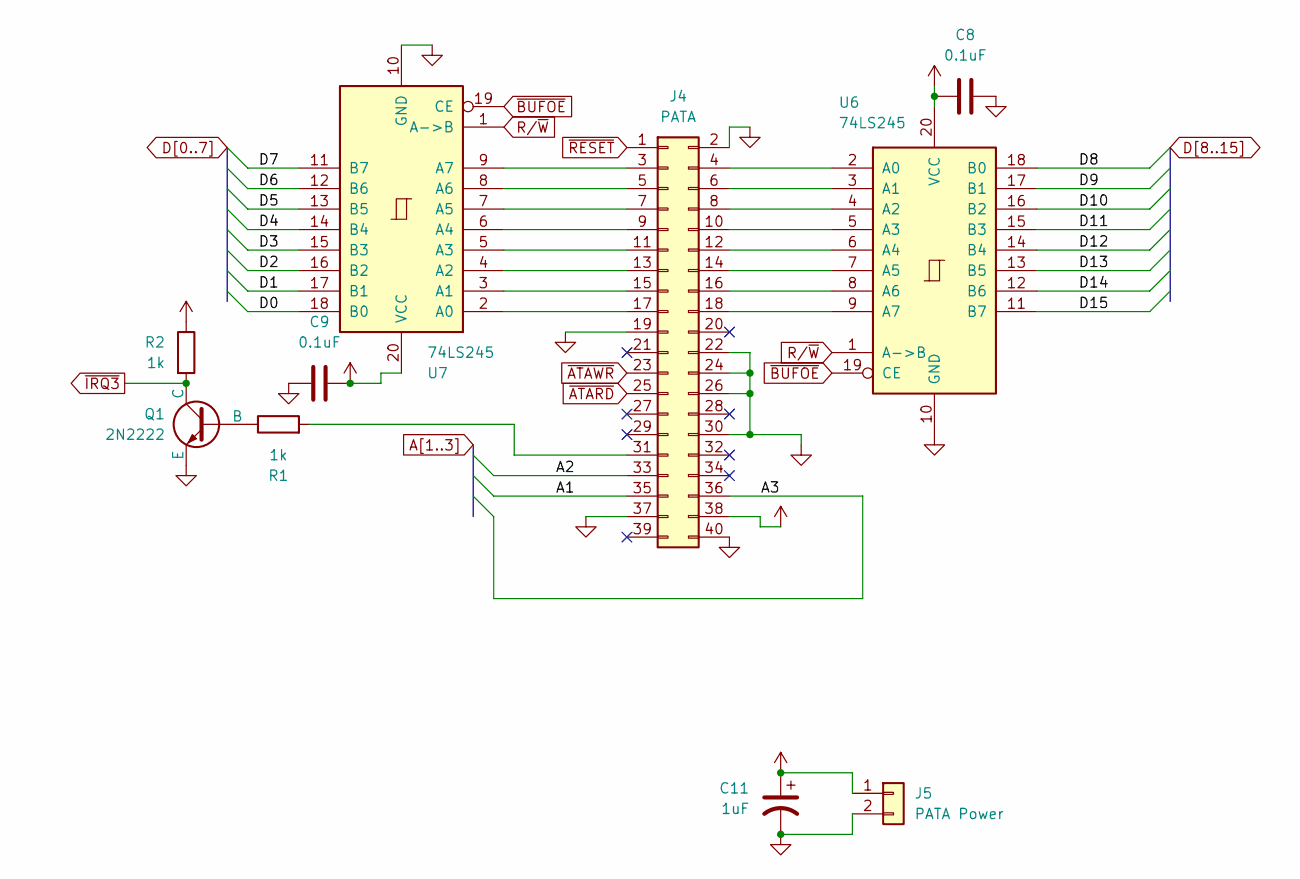
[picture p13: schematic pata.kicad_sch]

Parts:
C8, C9: 0.1uF; C_Disc_D5.0mm_W2.5mm_P5.00mm
C11: 1uF; CP_Radial_D5.0mm_P2.50mm
J4: PATA; IDC-Header_2x20_P2.54mm_Horizontal
J5: PATA Power; PinHeader_1x02_P2.54mm_Horizontal
Q1: 2N2222; TO-92
R1, R2: 1k; R_Axial_DIN0207_L6.3mm_D2.5mm_P7.62mm_Horizontal
U6, U7: 74LS245; DIP-20_W7.62mm_Socket

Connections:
A1: J4.35; also elsewhere on the board
A2: J4.33; also elsewhere on the board
A3: J4.36; also elsewhere on the board
D0: U7.18 (B0); also elsewhere on the board
D1: U7.17 (B1); also elsewhere on the board
D2: U7.16 (B2); also elsewhere on the board
D3: U7.15 (B3); also elsewhere on the board
D4: U7.14 (B4); also elsewhere on the board
D5: U7.13 (B5); also elsewhere on the board
D6: U7.12 (B6); also elsewhere on the board
D7: U7.11 (B7); also elsewhere on the board
D8: U6.18 (B0); also elsewhere on the board
D9: U6.17 (B1); also elsewhere on the board
D10: U6.16 (B2); also elsewhere on the board
D11: U6.15 (B3); also elsewhere on the board
D12: U6.14 (B4); also elsewhere on the board
D13: U6.13 (B5); also elsewhere on the board
D14: U6.12 (B6); also elsewhere on the board
D15: U6.11 (B7); also elsewhere on the board
GND: C8.2, C9.2, C11.2, J4.2, J4.19, J4.22, J4.24, J4.26, J4.30, J4.37, J4.40, J5.2, Q1.3 (E), U6.10 (GND), U7.10 (GND); also elsewhere on the board
unnamed: J4.3, U7.9 (A7)
unnamed: J4.4, U6.2 (A0)
unnamed: J4.5, U7.8 (A6)
unnamed: J4.6, U6.3 (A1)
unnamed: J4.7, U7.7 (A5)
unnamed: J4.8, U6.4 (A2)
unnamed: J4.9, U7.6 (A4)
unnamed: J4.10, U6.5 (A3)
unnamed: J4.11, U7.5 (A3)
unnamed: J4.12, U6.6 (A4)
unnamed: J4.13, U7.4 (A2)
unnamed: J4.14, U6.7 (A5)
unnamed: J4.15, U7.3 (A1)
unnamed: J4.16, U6.8 (A6)
unnamed: J4.17, U7.2 (A0)
unnamed: J4.18, U6.9 (A7)
unnamed: J4.31, R1.2
unnamed: Q1.2 (B), R1.1
R/~W: U6.1 (A->B), U7.1 (A->B); also elsewhere on the board
VCC: C8.1, C9.1, C11.1, J4.38, J5.1, R2.1, U6.20 (VCC), U7.20 (VCC); also elsewhere on the board
~ATARD: J4.25; also elsewhere on the board
~ATAWR: J4.23; also elsewhere on the board
~BUFOE: U6.19 (CE), U7.19 (CE); also elsewhere on the board
~IRQ3: Q1.1 (C), R2.2; also elsewhere on the board
~RESET: J4.1; also elsewhere on the board

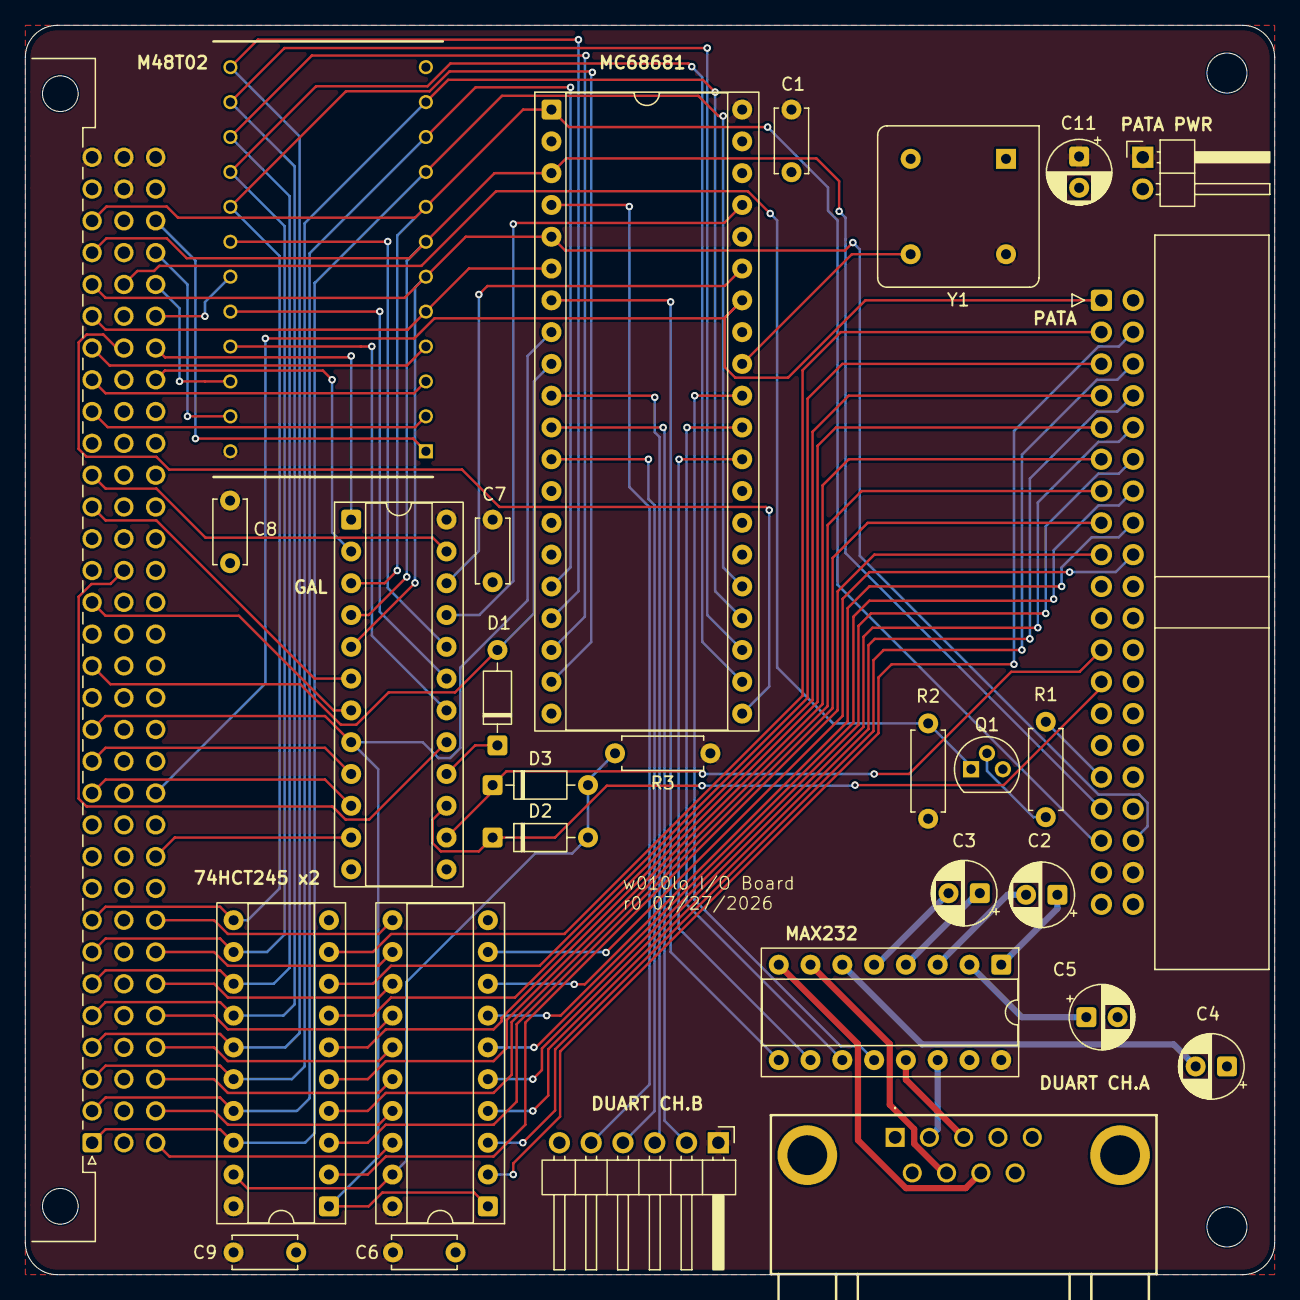
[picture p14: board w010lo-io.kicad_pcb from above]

Board: 4 copper layers, 99.8 x 99.8 mm, 31 parts (0 on the bottom side), 89 nets.

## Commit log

2026-05-05 Add schematic
2026-07-20 Add WIP Kicad files
    [backplane-slots.kicad_sch, w010lo-backplane.kicad_pcb, w010lo-backplane.kicad_sch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]
2026-07-28 Final Kicad update before manufacturing
    [backplane-slots.kicad_sch, pata.kicad_sch, rtc.kicad_sch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]
2026-08-10 Add fixes to kicad + new addrs in demos
    [w010lo-cpu.kicad_pcb, w010lo-cpu.kicad_sch, w010lo-mem.kicad_pcb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]
2026-09-13 Kicad files for OPL2 test
    [w010lo-sound-and-vision.kicad_pcb, w010lo-sound-and-vision.kicad_sch]
